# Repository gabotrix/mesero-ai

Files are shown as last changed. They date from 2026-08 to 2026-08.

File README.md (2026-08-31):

<div align="center">

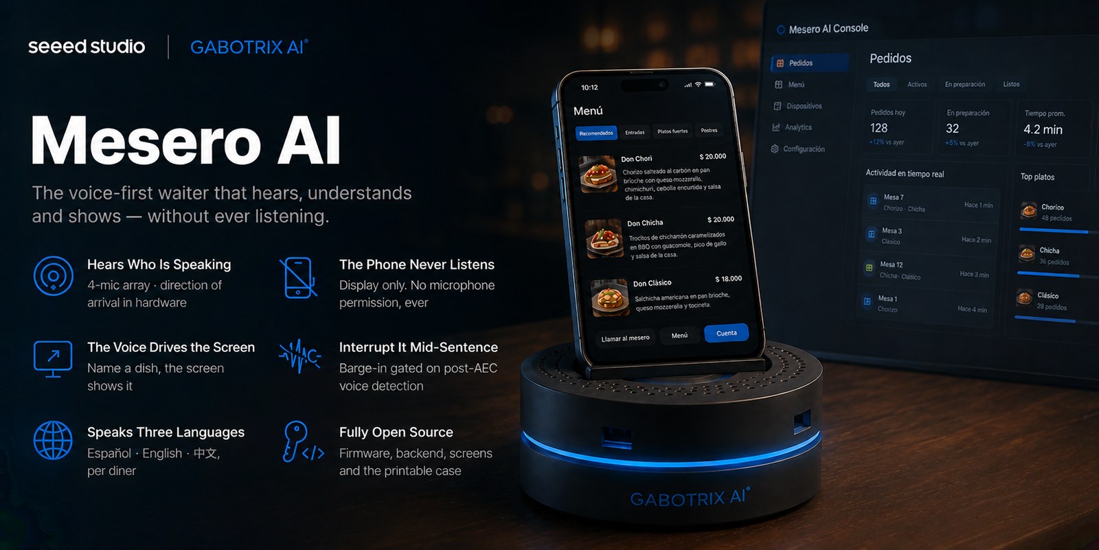
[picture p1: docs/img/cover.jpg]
Mesero AI — the voice-first waiter that hears, understands and shows, without ever listening. The printed dock holds a phone showing the menu, with the console behind it.


# Mesero AI

**A voice waiter that lives in the table, not in the phone.**

Diners talk to the table. The gadget listens and answers.
Their phone only follows along — and never asks for a microphone.






</div>

---

## The idea

A diner sits down, taps an NFC sticker on the table stand, and their phone opens
a screen bound to that table. From then on they simply **talk**. The order
appears on the screen as they say it, the kitchen sees it, the bill is paid from
the same page.

The interesting part is what the table hears. The reSpeaker's four-microphone
array reports the **direction** every phrase came from, so the agent knows *who
at the table is speaking* — and the ajiaco goes to the person who asked for it,
without anybody typing a seat number.

<div align="center">
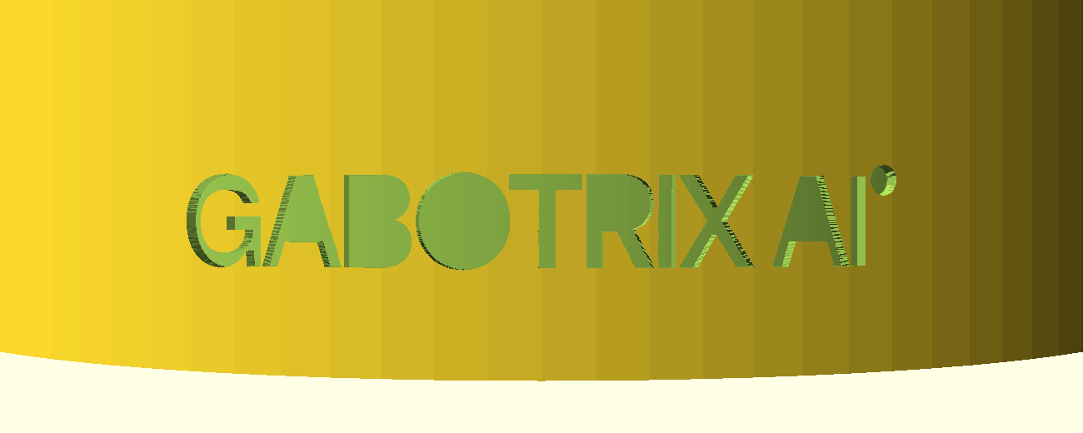
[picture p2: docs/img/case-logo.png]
The wordmark sunk into the front wall of the printed base

</div>

## Why the phone never touches the hardware

This is the decision everything else follows from.

iOS Safari has neither Web Bluetooth nor Web Serial, so a phone cannot pair with
the gadget even if we wanted it to. It also drops microphone permission the
moment the screen locks, which makes phone-side capture useless for a device
sitting on a table for an hour.

So the two never talk to each other. Both open a plain WebSocket to the backend
and are matched by a `dock` id — which is exactly what the NFC tag encodes.

```mermaid
flowchart LR
  A["reSpeaker XVF3800<br/>+ XIAO ESP32S3"] -- "WiFi · PCM16 16 kHz" --> B["Backend<br/><i>session, order, seats</i>"]
  C["Diner's phone<br/><i>NFC: ?dock=mesa-01</i>"] -- "WebSocket · display only" --> B
  B -- "realtime audio" --> D["Voice model"]
  B --> E["Kitchen board"]
  B --> F["POS · carta, tables"]
```

The tag is a passive NTAG213 sticker in the stand — no power, no pairing, and
every iPhone since the XS reads it natively. The board has no NFC and needs none.

## The firmware is deliberately dumb

It carries; it does not decide. It moves already-clean 16 kHz audio between I2S
and a WebSocket and reports the bearing. It does not know the menu, when a turn
ended, or which vendor answers.

That is on purpose, for four reasons: changing the menu must not mean unscrewing
a table; restarting a server takes a second where flashing and re-provisioning
take minutes; less code on the device is fewer failures somewhere with no serial
monitor attached; and the XMOS chip already does echo cancellation, beamforming
and noise suppression **in silicon**, so repeating it here would be slower and
worse.

## Build one

[`docs/build-guide.md`](docs/build-guide.md) takes you from an empty desk to a
table that takes an order out loud — about three hours, most of it printing. It
includes the calibration coupon to print before you commit four hours to a lid,
and a troubleshooting section where every entry is a failure we actually hit,
with what it looked like at the time.

## Quick start

You need the two Seeed boards, a speaker, and about twenty minutes.

```bash
git clone https://github.com/gabotrix/mesero-ai.git && cd mesero-ai
cd backend && npm install && node src/index.js
```

Open `http://localhost:8787/?dock=mesa-01` and the table screen is there, on the
carta committed in `backend/menu.json`, with the kitchen board and the POS
alongside it. No account and no configuration.

**The voice needs a venue key.** That part is a hosted service, and the key is
what identifies a restaurant to it. Create one in the console — free, self-serve
— and set one variable:

```bash
VENUE_KEY=msr_live_…
```

That is the whole configuration. No project ids, no API keys, nothing else: the
venue key is the only credential this backend ever carries, and its carta, its
tables and its agent arrive with it. The backend caches them to disk, so a
restaurant whose internet drops at seven in the evening still serves dinner.

Or bring your own. `PROVIDER=openai` talks to OpenAI with your credential;
`PROVIDER=local` talks to a model on your own hardware and keeps working when the
internet does not. Both mean you host the backend — we cannot reach a model on
your LAN, and we should not be holding your vendor key. The contract for a local
one is in [`docs/voz-local.md`](docs/voz-local.md); an adapter is about a hundred
lines.

Everything else in this repository runs without any of that — the wire protocol,
the firmware, the order state, the screens, the case.

No hardware yet? `device-client/` is a Python stand-in that speaks the same
protocol using your laptop's microphone.

## Bill of materials

| Part | Why |
| --- | --- |
| [reSpeaker XVF3800 + XIAO ESP32S3](https://wiki.seeedstudio.com/respeaker_xvf3800_xiao_getting_started/) | Four-mic array with hardware AEC, beamforming and direction of arrival |
| 8 Ω speaker, 50 × 45 × 22 mm | Seeed 114993346 fits the printed bay exactly |
| NTAG213 sticker, 25 mm | Passive. Sits under the phone cradle |
| ~90 g PETG | The case. PLA warps in a kitchen |
| 4 × M3 × 12 screws | Lid to base |

## Build it

**1 · Print the case.** Parametric OpenSCAD in [`hardware/case/`](hardware/case/).

```bash
openscad -D 'part="base"' -o base.stl hardware/case/mesero-dock.scad
openscad -D 'part="lid"'  -o lid.stl  hardware/case/mesero-dock.scad
```

Print `calib.stl` first — it verifies the mount circle and the connector cutouts
before you commit four hours to the lid. PETG, 0.2 mm, 4 walls, 25% infill.

<div align="center">
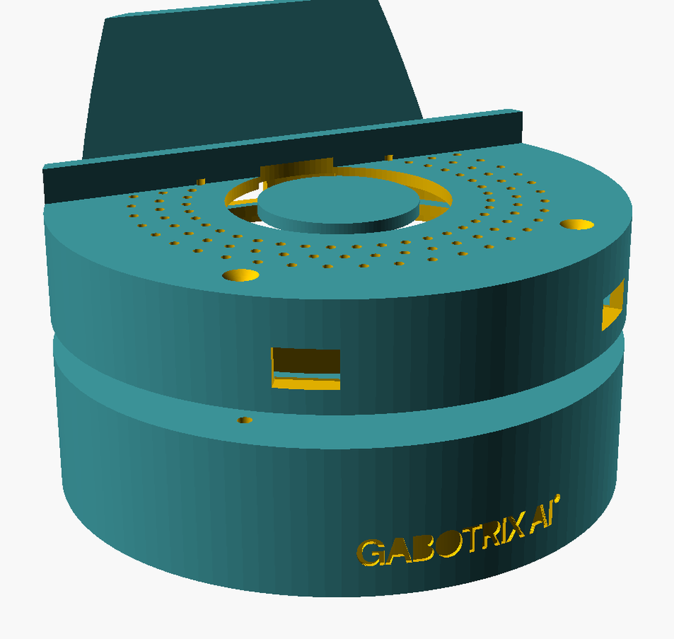
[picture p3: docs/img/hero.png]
The printed dock: a cylinder the size of the board, with a phone leaning into its cradle

</div>

**2 · Flash the firmware.**

```bash
cd firmware && pio run -t upload
```

On first boot it raises a WiFi portal named **MeseroAI-setup**. Join it from a
phone and the setup page asks for the network, the table id and the venue key —
or scan the QR the console prints for that table and every field arrives filled.

**3 · Run the backend.** Locally as above, or as a container:

```bash
docker build -t mesero-ai .
docker run -p 8787:8787 -e VENUE_KEY=msr_live_… mesero-ai
```

`deploy/cloud/` adds Caddy in front of it, which obtains and renews the
certificate on its own.

See [`docs/servidor.md`](docs/servidor.md) for where it should live and why a
diner's mobile data settles the question.

## What is in here

| Path | What it is |
| --- | --- |
| [`docs/build-guide.md`](docs/build-guide.md) | **Start here.** Empty desk to a talking table, and what every failure looks like when it happens |
| [`docs/protocolo.md`](docs/protocolo.md) | **The contract.** Binary audio frames plus JSON control, implemented identically by the firmware and the desktop client |
| [`firmware/`](firmware/) | ESP32S3 firmware — I2S, WebSocket, LED ring, setup portal |
| [`backend/`](backend/) | Session bridge: device audio ⇄ model, order state, screen fan-out |
| [`web/`](web/) | Table screen, kitchen board and POS. Static, no build step |
| [`hardware/case/`](hardware/case/) | Parametric case and phone cradle |
| [`device-client/`](device-client/) | Python stand-in for the gadget |
| [`deploy/`](deploy/) | Container and appliance deployments |
| [`docs/voz-local.md`](docs/voz-local.md) | Running the voice model on your own hardware |

## Design decisions worth knowing

Every one of these is a bug we shipped first.

**A turn ends when the speaker stops, not when the model does.** The backend
meters audio to the device at real time, so playback trails generation by the
length of the queue. Ending the turn at `turnComplete` opens the microphone while
the speaker is still talking — and the agent hears itself, answers itself, and
orders its own dinner.

**Barge-in is gated on the array's hardware VAD, not on level.** Measured echo
peaked at 22099 against speech at 32767; no threshold separates those reliably.
The XMOS chip already knows whether a human is talking, so ask it.

**Bearings are sampled while somebody speaks, never at tool-call time.** The
model answers seconds after a diner stops, by which point the azimuth register
holds something stale. Reading it there produced phantom customers sitting at
exactly 0° and exactly 90°.

**Every tuning constant is asserted numeric at boot.** Three of them were once
missing from the config, and `n >= undefined` is quietly `false` — so the
features simply switched themselves off with no error anywhere.

## License

Apache License 2.0 — see [LICENSE](LICENSE).

The hosted voice service that a venue key unlocks is operated by GABOTRIX and is
not part of this repository. Everything needed to build the device and run your
own server is.

<div align="center">
<sub>Built by <a href="https://gabotrix.com"><b>GABOTRIX</b></a> · OPENMARKT S.A.S.</sub>
</div>

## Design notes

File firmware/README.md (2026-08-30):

# Gadget firmware — reSpeaker XVF3800 + XIAO ESP32S3

The XMOS keeps its factory **I2S firmware** and does the hard part in silicon:
acoustic echo cancellation, beamforming, noise suppression, voice activity
detection and direction of arrival. This firmware only moves clean 16 kHz audio
between I2S and a WebSocket, and reports which seat is talking.

## Two ways to use the board, and which one you want

The board has two USB-C ports and two firmware personalities. Confusing them is
the single most common way to lose an afternoon.

| Port | Purpose |
|---|---|
| On the **XIAO module** | Flashing and serial for the ESP32S3 (`VID_303A`, `PID_1001`). Never carries audio. |
| On the **base board**, next to the 3.5 mm jack | XMOS: USB audio *and* DFU firmware updates. |

| Mode | What you get | When to use it |
|---|---|---|
| **I2S** (factory default) | The XIAO reads the array over I2S and streams over WiFi. The board does **not** enumerate on USB at all. | The product. This firmware. |
| **USB** | The array is an ordinary USB microphone and speaker on a PC. The XIAO is out of the audio path. | Fastest way to demo the array with `device-client/`, and useful for isolating audio problems. |

If nothing at all appears when you plug the base-board port in, that is not a
broken cable — it is I2S mode behaving exactly as documented.

## Switching modes (DFU)

Flashing the XMOS needs **safe mode**, because the I2S firmware does not support
USB DFU on its own.

1. Connect the **base board** USB-C port — the one next to the 3.5 mm jack.
2. Hold the **Mute** button, and while holding it, reconnect power.
   The red LED starts blinking: that is safe mode.
3. Flash:

```bash
dfu-util -R -e -a 1 -D respeaker_xvf3800_usb_dfu_firmware_v2.0.x.bin
```

Firmware images live in the
[reSpeaker_XVF3800_USB_4MIC_ARRAY](https://github.com/respeaker/reSpeaker_XVF3800_USB_4MIC_ARRAY)
repository:

| File | Mode |
|---|---|
| `respeaker_xvf3800_usb_dfu_firmware_v2.0.x.bin` | USB, 2 channels |
| `respeaker_xvf3800_usb_dfu_firmware_6chl_v2.0.x.bin` | USB, 6 channels |
| `respeaker_xvf3800_i2s_dfu_firmware_v1.0.x.bin` | I2S — flash this to come back |

It is fully reversible. Going to USB mode to demo and back to I2S mode to ship is
a normal thing to do.

Get `dfu-util` with `brew install dfu-util`, `sudo apt install dfu-util`, or the
Windows binaries from the dfu-util site (add the folder to `PATH`, then check
with `dfu-util -V`).

## Pinout

Confirmed against Seeed's own I2S and UDP-streaming examples for this board.

| Signal | GPIO |
|---|---|
| I2S BCLK | 8 |
| I2S WS / LRCLK | 7 |
| I2S data out (→ speaker) | 44 |
| I2S data in (mics →) | 43 |
| XMOS control | I2C, address `0x2C` |

The XMOS delivers **16 kHz, stereo, 32-bit**; the wire protocol is 16-bit mono.
The conversion — left channel, top 16 bits — is in `captureAndSend()`.

### XMOS control registers

| Function | ResID | Cmd | Notes |
|---|---|---|---|
| DOA value | 20 | 18 | 4 bytes: `uint16` azimuth 0–359, `uint16` speech flag |
| LED effect | 20 | 12 | |
| LED brightness | 20 | 13 | |
| LED speed | 20 | 15 | |
| LED colour | 20 | 16 | 3 bytes RGB |

Direction of arrival and voice activity come straight from the array, which is
why the protocol carries `doa` in the audio header instead of guessing on the
microcontroller.

## Build and flash

```bash
cd firmware
pio run                 # compile
pio run -t upload       # flash over the XIAO's USB-C port
pio device monitor      # serial log
```

Without `pio` on your PATH, use `python -m platformio` instead.

## Provisioning

No credentials are compiled in. On first boot the gadget opens a WiFi access
point called **`MeseroAI-setup`**. Join it and a captive portal asks for:

- the WiFi network and password
- the backend host or IP, and port (default `8787`)
- the table id — the `dock`, which must match the NFC tag's `?dock=` value

Settings persist in NVS. To forget them, hold the **BOOT** button on the XIAO
while resetting; the portal reopens.

## What the LED ring is telling you

| Colour | Meaning |
|---|---|
| Barely lit | Idle — nobody has woken the table |
| Amber | Listening |
| Violet | Thinking |
| Warm orange | The agent is talking |

## Behaviour worth knowing

**The microphone never mutes.** The gadget streams even while the agent speaks,
because the XVF3800 removes the speaker's echo in hardware. That is what makes
interrupting it feel natural.

**Barge-in is obeyed instantly.** On `audio_reset` the firmware clears both its
ring buffer and the I2S DMA buffers. Draining a queued sentence after the diner
starts talking is what makes a voice assistant feel deaf.

**Playback is capped at 400 ms.** If the network stalls and recovers, the gadget
drops the backlog rather than replaying a sentence that is no longer relevant.

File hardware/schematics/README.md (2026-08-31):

# Schematics

Two drawings. Between them they account for every connection in the build.

| File | What it shows |
|---|---|
| `mesero-ai-conexiones` | The whole system: the dock, the diner's phone, your server, and which of them are wired to which. The short answer is that the phone is wired to nothing. |
| `mesero-ai-pines` | The six signals that cross between the XIAO and the XVF3800, with the pin each one lands on. |

Each exists as `.svg` (source), `.png` (2× for the web) and `.pdf` (for print).

## There is no circuit to draw

This is worth saying plainly, because a project with a microphone array and an
amplifier sounds like it should have one. It does not. The XIAO seats directly
onto the reSpeaker's 14-pin header, the speaker plugs into a connector that is
already fitted, and the NFC tag is a passive sticker with no electrical
connection to anything. Nothing is soldered during the build and there is no
breadboard stage.

What *is* worth drawing is the signal map, because those pin numbers are the
part you cannot guess, and the isolation between the phone and the gadget,
because it is the design decision the whole project rests on.

## Where the numbers come from

Every pin in `mesero-ai-pines` is read out of the firmware in this repository,
not from a datasheet:

| Signal | GPIO | XIAO pin | Read from |
|---|---|---|---|
| I²S BCLK | 8 | D9 | `firmware/src/main.cpp` — `PIN_I2S_BCLK` |
| I²S WS | 7 | D8 | `firmware/src/main.cpp` — `PIN_I2S_WS` |
| I²S DOUT | 44 | D7 | `firmware/src/main.cpp` — `PIN_I2S_DOUT` |
| I²S DIN | 43 | D6 | `firmware/src/main.cpp` — `PIN_I2S_DIN` |
| I²C SDA | 5 | D4 | `Wire.begin()` with no arguments — the XIAO ESP32S3 variant default |
| I²C SCL | 6 | D5 | as above |
| BOOT | 0 | — | `firmware/src/main.cpp` — `PIN_BOOT_BUTTON` |

The XVF3800 answers on I²C address `0x2C` at 100 kHz (`firmware/src/xvf3800.h`).

## Regenerating them

```bash
pip install svglib reportlab rlPyCairo
python esquemas.py
```

The drawings are generated rather than drawn by hand so that a pin which moves
in the firmware can be corrected in one place. Arrowheads are emitted as
polygons instead of SVG markers on purpose: the renderer that produces the PNG
and the PDF ignores markers, which would quietly strip every direction out of a
signal diagram and leave it looking finished.

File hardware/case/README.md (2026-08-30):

# Table dock — 3D printable enclosure

A cylinder the size of the board, with a small cradle standing on the lid. The
array lies flat on top facing the room, the 5 W driver fires down through the
floor beneath it, and the phone leans back against the cradle. That is the whole
object — no rear lobe, no slots, no pockets.

## Dimensions, and where they come from

These are read from the Seeed datasheets, not estimated:

| Value | Source |
|---|---|
| Board ⌀ 102 × 10 mm | `114993700` — listed as 102 × 102 × 10, and the board is round, so that is a boxed circle |
| Microphone circle 66 mm | `114993700` comparison table, XVF3800 column |
| Speaker 50 × 45 × 22 mm | `114993346` — rectangular with mounting ears |

Still unverified, and the reason the coupon exists:

| Parameter | What to measure |
|---|---|
| `mount_hole_dia` | The screw holes on the board |
| `mount_circle_dia` | Diameter of the circle those holes sit on |
| `mount_first_angle` | Where the first hole sits, measured from the front |

## Resulting dock

```
diameter    107.5 mm — a circle, nothing more
body        44.8 mm tall
overall     74.8 mm with the backrest
cradle      66 mm wide, 30 mm backrest, 15 mm gap, leaning 14 deg
```

## Print the coupon first

```bash
openscad -D 'part="calib"' -o calib.stl mesero-dock.scad
```

Ten minutes of filament against four hours for the base. Drop the board in: if
the screws miss, fix `mount_circle_dia` and `mount_first_angle` before printing
anything else.

## Parts

```bash
openscad -D 'part="base"' -o base.stl mesero-dock.scad
openscad -D 'part="lid"'  -o lid.stl  mesero-dock.scad
```

| Part | Notes |
|---|---|
| `base` | Speaker bay, floor vents, cable route, feet |
| `lid` | Microphone ports on the 66 mm circle, LED slot, connector cutouts, phone cradle, NFC pocket |
| `calib` | Fit gauge |

## Print settings

| Setting | Value | Why |
|---|---|---|
| Material | PETG | A table gets wiped with hot cloths and sits in sunlight; PLA sags |
| Nozzle | 0.4 mm | The microphone ports are 1.8 mm |
| Layer | 0.2 mm | |
| Infill | 20 % gyroid | Damps the panel resonance a 5 W driver excites |
| Supports | None | The groove leans 18 deg off vertical; ports print vertically |

## Bill of materials

| Item | Qty |
|---|---|
| M3 × 12 self-tapping screws | 4 |
| 12 mm silicone feet | 3 |
| NTAG213 sticker, 25 mm round | 1 |
| Speaker 114993346 | 1 |

## Three things the renders caught

Each of these was found by looking at an orthographic view, not by reading the
code. Render before printing.

**The board is 102 mm, not 65.** The first version was built around a guess.
Reading the datasheet replaced six estimates with three measured values.

**Ports drilled straight through the cradle.** The microphone holes were cut
after the cradle was unioned onto the plate, so every hole under the backrest
went through it. They are now cut to the plate thickness only, and skipped
entirely in the sector the cradle occupies — a hole into solid plastic is not a
port, it is a weakened joint.

**Strength had to come from the attachment, not the shape.** A flat 3 mm plate
standing 30 mm tall, printed with its layers lying in the bending plane, snaps at
the root the first time somebody leans a phone on it — and the gussets propping
it up poked outside the case.

Curving the wall to follow the rim fixed the strength and broke the function: a
phone is flat, so it touched a concave wall only at its two edges and rocked
between them. The contact face is flat again, and the wall now spans a chord and
is intersected with the body, so both ends merge into the case rim. That makes it
a beam held at both ends rather than a plate cantilevered off the lid, which is
the thing that fails. Its section runs 6.2 mm at the root to 3.2 mm at the lip.

**The lean was mirrored.** The first version reclined the phone forward, over the
microphone array. Sign error in the rotation, caught in an orthographic side
view — never in isometric.

**A phone stand on top shadows the rear microphone.** This is unavoidable, not a
bug: something has to hold the phone, and it has to stand somewhere. The cradle
sits at the rim to shadow as little of the band as possible, and the diner is in
front of the dock, where the array is unobstructed.

## Still to verify on the bench

- The three mounting parameters above
- Whether the connector cutout angles in `lid()` match how the board is rotated
  when it is fitted — those are placed, not measured

## The maker's mark

The GABOTRIX wordmark is sunk 0.8 mm into the front wall of the base, to be
filled by hand after printing — paint, a drop of resin, or a scrap of filament
pressed in warm.

It is **wrapped** around the cylinder, not projected flat onto it, and that is
not a stylistic choice. A 40 mm chord on this 53.75 mm radius falls 3.9 mm away
from the surface at its ends, while the wall is only 2.4 mm thick: a
flat-bottomed pocket would cut clean through the case before it reached the
middle of the word. So the outline is sliced into 60 thin vertical strips and
each is cut radially at its own angle, which keeps the depth the same everywhere.

The outline lives in `gabotrix-logo.svg`, traced from the PNG. To use a different
mark, replace that file and adjust `logo_aspect` to its width ÷ height. To move
or resize it:

| Parameter | What it does |
|---|---|
| `logo_w` | Arc length along the wall, in mm. |
| `logo_z` | Height of its centre above the table. |
| `logo_depth` | Recess depth. Keep it well under `wall` (2.4 mm). |
| `logo_angle` | Where it sits. 90° faces the diner; the cable exit is at 270°. |
| `logo_slices` | Strips used to bend it. 60 keeps the error under a micron. |

Set `logo_w = 0` to leave the wall plain — but note the recess is what makes the
case feel finished, and it costs nothing to print.

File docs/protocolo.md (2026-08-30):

# Protocolo dispositivo ↔ backend (v1)

Este documento es **normativo**: el firmware del ESP32S3 y el cliente mock de escritorio
deben implementarlo de forma idéntica. Si cambias algo aquí, cambian los dos.

## 1. Transporte

Un único WebSocket por dispositivo.

```
ws://<host>:8787/device?dock=mesa-01&token=<device_token>
```

| Parámetro | Obligatorio | Descripción |
|---|---|---|
| `dock` | sí | Identificador de la mesa/soporte. Es lo que ata el gadget a la pantalla del teléfono. |
| `token`  | no (dev) | Token del dispositivo. En desarrollo se acepta ausente. |

Sobre ese mismo socket viajan dos tipos de frame, y **el tipo de frame decide el
significado**:

- **Frames de texto** → mensajes de control en JSON.
- **Frames binarios** → audio PCM.

Esta separación evita base64 (que infla 33 % y quema CPU en el ESP32) y permite al
firmware escribir el audio directo desde el buffer de I2S.

## 2. Frames binarios de audio

Cabecera de **8 bytes**, little-endian, seguida de las muestras PCM.

```
 offset  size  campo      descripción
 ------  ----  ---------  ----------------------------------------------------
   0      1    magic      0xA5
   1      1    version    0x01
   2      1    type       0x01 = mic (dispositivo → backend)
                          0x02 = speaker (backend → dispositivo)
   3      1    flags      bit0 = VAD activo
                          bit1 = fin de locución
                          bit2 = frame de confort/silencio
   4      2    seq        uint16, incrementa por frame, envuelve en 0xFFFF
   6      2    doa        uint16, grados 0..359. 0xFFFF = desconocido
   8      N    pcm        PCM16 little-endian, mono
```

**Formato de audio fijo en v1:** 16 kHz, 16 bits con signo, mono.
**Tamaño de frame recomendado:** 20 ms = 320 muestras = 640 bytes de PCM → 648 bytes en total.

> El backend reamplifica/reamostrea a lo que pida el proveedor de voz (hoy 24 kHz).
> El dispositivo **siempre** habla 16 kHz. Así el firmware queda tonto y estable.

`doa` viaja en la cabecera de audio, no en JSON, porque cambia por frame y sirve para
saber **quién** de la mesa está hablando sin coste de parseo.

## 3. Mensajes JSON — dispositivo → backend

Todos llevan `t` (type).

### `hello` — primer mensaje tras conectar
```json
{
  "t": "hello",
  "proto": 1,
  "dock": "mesa-01",
  "device": { "id": "xiao-68ee8f51e544", "model": "respeaker-xvf3800", "fw": "0.1.0" },
  "audio":  { "rate": 16000, "bits": 16, "ch": 1, "frameMs": 20 },
  "caps":   ["doa", "vad", "aec", "beamforming"]
}
```

### `telemetry` — máximo 5 Hz
```json
{ "t": "telemetry", "vad": true, "doa": 143, "rms": 2210 }
```

### `button` — pulsador físico del soporte
```json
{ "t": "button", "id": "call_waiter" }
```

### `bye`
```json
{ "t": "bye", "reason": "power_off" }
```

## 4. Mensajes JSON — backend → dispositivo

### `welcome` — respuesta a `hello`
```json
{
  "t": "welcome",
  "session": "s_9f3a…",
  "audio": { "rate": 16000, "bits": 16, "ch": 1, "frameMs": 20 },
  "keepaliveMs": 15000
}
```

### `agent_state` — para LEDs y para saber si hay que atenuar el micrófono
```json
{ "t": "agent_state", "state": "listening" }
```
`state` ∈ `idle` | `listening` | `thinking` | `talking`.

### `audio_reset` — **barge-in**
```json
{ "t": "audio_reset" }
```
El dispositivo debe **vaciar de inmediato** su buffer de reproducción y callar el parlante.
Es el mensaje más importante para que la interrupción se sienta natural: si el firmware
sigue drenando su buffer, el cliente escucha al agente hablando encima de él.

### `led`
```json
{ "t": "led", "mode": "listening", "doa": 143 }
```

### `ping` / `pong`
El backend manda `{"t":"ping","ts":…}` cada `keepaliveMs`. El dispositivo responde
`{"t":"pong","ts":…}` con el mismo `ts`. Si el dispositivo no ve un `ping` en
`3 × keepaliveMs`, reconecta.

## 5. Reglas de comportamiento

1. **Orden de apertura.** El dispositivo no envía audio hasta recibir `welcome`.
2. **Reconexión.** Backoff exponencial con jitter: 0.5 s, 1 s, 2 s, 4 s, máx. 10 s.
   Al reconectar con el mismo `dock`, el backend reengancha la sesión existente si
   sigue viva (ventana de 60 s), así el pedido no se pierde.
3. **Barge-in.** El dispositivo transmite el micrófono **siempre**, incluso mientras el
   agente habla. El AEC del XVF3800 ya quita el eco del parlante, así que no hay que
   silenciar el micro. La decisión de interrumpir la toma el backend.
4. **Jitter buffer.** El dispositivo debe acumular ~60 ms antes de empezar a reproducir,
   y descartar el frame más viejo si el buffer supera 400 ms.
5. **Sin audio que enviar.** Si no hay voz, el dispositivo puede omitir frames; no debe
   mandar silencio continuo salvo que quiera mantener el AEC alimentado (`flags` bit2).

## 6. Canal de la pantalla (backend ↔ Web UI)

Segundo WebSocket, **solo JSON**, que es lo que hace que el teléfono siga al gadget:

```
ws://<host>:8787/ui?dock=mesa-01
```

El backend manda un `snapshot` al conectar y luego parches:

```json
{ "t": "snapshot", "session": "s_9f3a…", "agentState": "listening",
  "screen": "menu", "order": { "items": [], "total": 0 }, "transcript": [] }

{ "t": "agent_state", "state": "talking" }
{ "t": "transcript", "role": "user", "text": "quiero una bandeja paisa" }
{ "t": "order", "items": [ { "sku": "bandeja-paisa", "qty": 1, "price": 32000 } ], "total": 32000 }
{ "t": "screen", "name": "order_review" }
{ "t": "payment", "status": "pending", "url": "https://checkout.wompi.co/l/…" }
```

Además, para que la pantalla y el POS sigan la cocina y la carta en vivo:

```json
{ "t": "vad", "vad": true }
{ "t": "menu", "menu": { "restaurant": "…", "categories": [ … ] } }
```

- `vad` refleja si el micrófono está oyendo voz; la pantalla lo usa para animar
  el anillo cuando habla el cliente (cuando habla el agente ya llega `agent_state`).
- `menu` se emite a todas las mesas cuando el POS guarda la carta.

Dentro de `state` viajan también los **tickets**: cada `confirm_order` congela la
ronda en `state.tickets[]` (`{ id, n, status, sentAt }`), y los items confirmados
llevan `ticket: <id>`. `status` ∈ `kitchen` | `preparing` | `ready` | `served`, y lo
avanza el POS por HTTP:

```
PUT  /api/menu                                  guarda la carta (CRUD del POS)
POST /api/dock/:dock/ticket/:id/status          { "status": "preparing" }
POST /api/dock/:dock/reset                      libera la mesa
POST /api/dock/:dock/tool                       { "name": "add_item", "args": {…}, "doa": 40 }
```

`/tool` aplica una herramienta del pack como si la hubiera llamado el modelo —
mismo reducer, mismo fan-out — y es lo que usa un demo o un POS para editar un
pedido a mano.

La UI es **solo pantalla**: no captura audio y no manda comandos de voz. Lo único que
puede emitir es interacción táctil de respaldo:

```json
{ "t": "ui_action", "action": "call_waiter" }
```

## 7. Por qué así

- **Un solo socket para audio y control** evita desincronización entre el estado del
  agente y el audio que se está reproduciendo, y ahorra un TLS en el ESP32.
- **Binario crudo para audio** mantiene el firmware simple y el ancho de banda bajo:
  16 kHz mono PCM16 = 256 kbps por sentido, cómodo para WiFi de restaurante.
- **El dispositivo no sabe nada del proveedor de voz.** Puede cambiarse OpenAI Realtime
  por Azure o Gemini sin tocar el firmware. Esa es la razón de que el backend reamostree
  en vez de exigirle 24 kHz al ESP32.

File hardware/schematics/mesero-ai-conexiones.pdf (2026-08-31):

# Mesero AI — connection diagram

Every connection in the build. The gadget hears; the phone only shows.

GABOTRIX AI®
reSpeaker XVF3800 + XIAO ESP32S3

ON THE TABLE — THE GADGET

## reSpeaker XVF3800

Seeed 114993700 · XMOS DSP · firmware 1.0.5
4 microphones on a 66 mm circle
Echo cancellation, beamforming, VAD, direction of arrival Class-D amplifier on board

I²S audio
16 kHz · 32 bit

I²C control
0x2C · 100 kHz

## XIAO ESP32S3

Seats on the array's 14-pin header — no loose wires Streams 20 ms PCM frames; holds Wi-Fi and the venue key BOOT on GPIO0: 3 s clears Wi-Fi · 10 s clears everything

amplified out

## Speaker · 8 Ω, 5 W

Seeed 114993346 · 50 × 45 × 22 mm Fires down through the floor of the base

USB-C — 5 V
power · flashing · provisioning

NTAG213 sticker
passive — no power, no wires

THE DINER'S PHONE

Menu
Order
Bill

Display only — never a microphone A web page, not an app
Opened by the tag: ?dock=mesa-01

tap

YOUR SERVER

## Node backend

Railway, a VPS, or a Seeed reComputer Speech in · order state · speech out
Seat attribution from the array's bearing Holds the venue key — the only credential railway.json health-checks /api/health

### Console — seeed.gabotrix.com

Menu, tables, brand, agent language
Kitchen screen — no second system to log into Flashes the gadget and puts it on the Wi-Fi, over USB from the browser (Web Serial)
Stores configuration, never a diner's order

WebSocket · binary PCM16

↕ the phone's own WebSocket — JSON screen state, no audio

No link between them, by design

The phone and the gadget never talk to each other. No Bluetooth, no pairing, no local socket.

Each opens its own connection to the backend and they are matched by the table id in the NFC tag.

That is why the phone never needs the microphone, and why a locked screen does not stop the order.

The only soldered joint in the build is the speaker's, and it arrives already made. Everything else plugs together.
Audio path: 4 microphones → XVF3800 (echo cancellation, beamforming) → I²S → ESP32-S3 → Wi-Fi → backend → back down the same socket → amplifier → speaker.

Apache-2.0 · github.com/gabotrix/mesero-ai · Seeed Interactive Signage Contest 2026

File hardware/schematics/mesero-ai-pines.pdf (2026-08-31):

# Mesero AI — board-to-board signals

Six signals cross between the two boards. Every number here is read from the firmware.

GABOTRIX AI®
No wiring — a 14-pin board-to-board seat

## XIAO ESP32S3

I²S master · Wi-Fi · USB-C

## reSpeaker XVF3800

XMOS DSP · I²S slave · amplifier

D9 · GPIO8 | I²S BCLK — bit clock | clock in
D8 · GPIO7 | I²S WS — word select | frame in
D7 · GPIO44 | I²S DOUT — the agent's voice, out to the speaker | to the amplifier
D6 · GPIO43 | I²S DIN — the room, already cleaned up | from the microphones
D4 · GPIO5 | I²C SDA — data | address 0x2C
D5 · GPIO6 | I²C SCL — clock, 100 kHz | bearing, LED ring

The audio format, both directions

16 000 Hz · 32-bit slots · stereo frame · I²S standard
One DMA block = 20 ms = 320 samples = 640 bytes of PCM16 The ESP32 is the master; the XVF3800 follows its clock
MCLK is not connected — the DSP makes its own

What I²C is for — and the trap inside it

The control channel reads which direction a phrase came from. That is what puts each dish on the right diner's tab, and what drives the LED ring.
It answers only on XVF3800 firmware 1.0.5. On 1.0.4 the register returns 65535 for ever: the gadget still takes orders, but cannot tell two diners apart.

Apache-2.0 · github.com/gabotrix/mesero-ai · Seeed Interactive Signage Contest 2026

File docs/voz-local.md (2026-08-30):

# Running the voice model yourself

Three ways to give this project a voice. Pick one with `PROVIDER`.

| | What you configure | Where the secret lives |
| --- | --- | --- |
| `gabotrix` *(default)* | A venue key | Nowhere near you |
| `openai` | Your own `OPENAI_API_KEY` | On your machine |
| `local` | A URL on your network | There is no secret |

The device, the session and the table screen cannot tell which one is running.
Adding a fourth is one file in `backend/src/providers/` and a branch in the
factory.

Note that `openai` and `local` both mean **you host the backend**. That is not a
restriction we invented — we cannot reach a model on your LAN, and we should not
be holding your vendor key.

## Why you might want `local`

Not privacy, though you get it. Not cost, though it is lower. The reason is that
a restaurant with bad internet still has to serve dinner, and every other option
here dies with the connection.

A reComputer R1025 or any small Linux box will do. What runs on it is your
choice — whisper.cpp for speech, a small instruct model, Piper for the voice —
because this project does not care, as long as the thing in front of them speaks
the envelope below.

## The contract

One WebSocket. JSON both ways. Audio is PCM16LE mono at 24 kHz, base64-encoded.
It is the same shape the hosted bridge speaks, on purpose: an adapter is about a
hundred lines, not a rewrite.

```
PROVIDER=local
LOCAL_VOICE_URL=ws://recomputer.local:8080/voice
# LOCAL_VOICE_TOKEN=            optional; a box on your own LAN has nobody to prove itself to
```

### Backend → you

| Message | When |
| --- | --- |
| `{"type":"session.update","session":{"instructions":"…","tools":[…]}}` | First thing on connect. The persona and the tools the agent may call. Ignore it and the agent still talks — it just will not know the carta. |
| `{"realtimeInput":{"audio":{"data":"<b64>","mimeType":"audio/pcm;rate=24000"}}}` | Microphone audio, continuously. |
| `{"textMessage":"…"}` | A user turn injected as text, from a button on the table screen. |
| `{"type":"response.cancel"}` | Somebody talked over the agent. Stop generating now. |

### You → backend

| Message | Meaning |
| --- | --- |
| `{"setupComplete":true}` | Ready. Nothing is sent until this arrives. |
| `{"serverContent":{"modelTurn":{"parts":[{"inlineData":{"data":"<b64>"}}]}}}` | Speech, as it is produced. Send it in pieces; do not wait for the sentence. |
| `{"serverContent":{"turnComplete":true}}` | You finished generating. |
| `{"serverContent":{"interrupted":true}}` | You noticed the diner talking over you first. |
| `{"toolCall":{"functionCalls":[{"id":"…","name":"add_item","args":{…}}]}}` | The agent wants to change the order. |
| `{"error":"…"}` | Anything that went wrong. |

## Two things that will bite you

**`turnComplete` is not the end of the turn.** It means you stopped generating.
The backend meters audio to the gadget at real time, so playback trails
generation by the length of the queue. Treating it as the end opens the
microphone while the speaker is still talking, and the agent hears itself,
answers itself, and orders its own dinner. We shipped that bug. The backend
handles this — you just need to know that `turnComplete` is about you, not about
the table.

**Send audio in pieces.** A whole sentence delivered at once overruns the
device's buffer and comes out chopped. The backend meters what you send, but it
cannot smooth what it never received.

## Latency, honestly

The hosted path answers in well under a second. A small model on a Pi-class box
will not, and the gap is most of a second of somebody sitting at a table waiting.
It is a real trade, not a footnote: a slower agent that always works may still be
the right answer for a restaurant whose internet drops at seven in the evening,
but decide it knowing that is the choice.

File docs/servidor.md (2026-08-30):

# Where the backend runs

Short answer: hosted, with a public name and a certificate. Everything else in
this page is either why, or the exception.

## The constraint that decides it

**A diner uses their own mobile data.** They tap an NFC tag and expect a page,
and they are not going to join the restaurant's WiFi first — on iOS that means
fighting a captive portal before dinner.

That single fact rules out every local arrangement for the *table screen*. A page
served from `192.168.1.50` is unreachable from a phone on a cellular network, and
a tunnel from a machine behind the bar is a workaround for a problem that
disappears if the backend simply lives somewhere with an address.

So: one hosted backend. The gadget dials `wss://` outbound from the restaurant
WiFi, the diner's phone opens `https://`, and there is nothing in the restaurant
to install, forward, or keep switched on.

## Why it cannot be a Supabase function

Four things the backend does, and none of them fit a short stateless request:

1. **Meters speech in real time.** The model emits a whole sentence at once. Sent
   onward as it arrives it overruns the device buffer and the reply comes out
   chopped, so frames go out on a 20 ms tick for the length of the meal, with
   16 ↔ 24 kHz resampling both ways.
2. **Knows when a turn ended** — when the speaker finishes, not when the model
   stops generating. Get that wrong and the agent hears itself, answers itself,
   and orders its own dinner. We shipped that bug once.
3. **Separates customers by bearing**, sampling angles only while somebody is
   actually speaking and averaging them circularly.
4. **Holds the order** and fans it out to every screen watching that table.

The Supabase function in this project does exactly one thing — relay audio to the
model — and knows nothing about tables.

## Deploying it

```bash
cp deploy/cloud/.env.example deploy/cloud/.env    # fill in the venue key
# point your domain at the host, then:
docker compose -f deploy/cloud/docker-compose.yml up -d
```

Caddy obtains and renews the certificate on its own; there is nothing else to
configure. The gadget's WebSocket and the diner's page go through the same proxy.

The gadget ships pointing at the hosted backend on port 443 and speaks TLS. The
setup portal still shows a server field, but behind a heading that says it is
only for somebody running their own — most people never touch it.

## The exceptions

**A restaurant with no reliable internet.** Then the whole thing has to be local,
including the model, and that is the offline mode — still unbuilt, and blocked on
the reComputer's power supply. Note that in this case the diner's phone must be
on the restaurant's WiFi; there is no way around it, because there is no public
address to reach.

**Somebody who wants to run their own backend** — a chain with its own
infrastructure, or a replicator who does not want to depend on us. Two supported
shapes:

- `deploy/recomputer/install.sh` — installs it as a systemd service on a
  reComputer R1025. Data lives in `/var/lib/mesero-ai` so an update never
  overwrites a carta somebody changed mid-service.
- `desktop/build.mjs` — builds the backend into a single executable for a
  Windows PC. It has no interface: it is a service, and it prints its addresses
  and then serves. If it ever becomes something a restaurant installs by itself
  it needs a real front end, and right now it is not on that path.

Both of these serve a LAN address, which means the diner's phone has to be on the
restaurant's WiFi. That is the trade, and it is the reason the hosted deployment
is the default rather than one option among three.

## Do not forward a port

If you run this locally anyway, do not open a port to it. The table screen has no
authentication — deliberately, because a diner cannot be asked to log in — and
that is only safe while reaching it requires being on the premises. Use an
outbound tunnel (`cloudflared tunnel --url http://localhost:8787`) if you need it
reachable, so there is no inbound hole in the firewall.

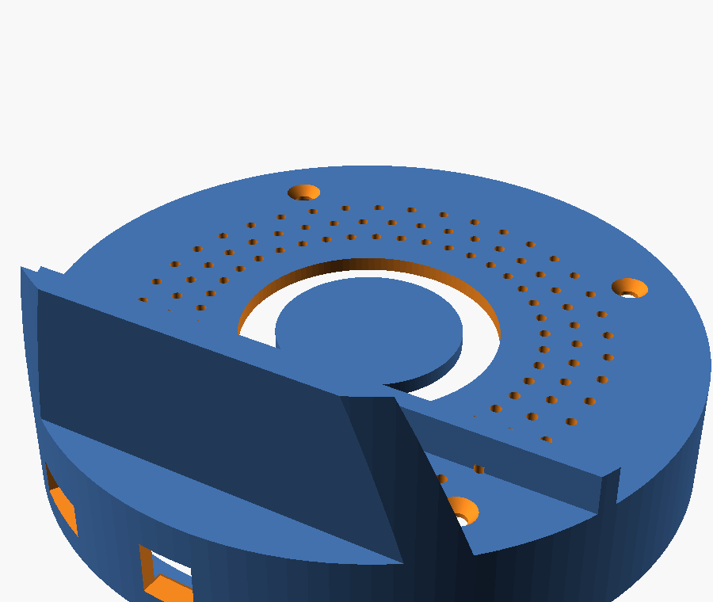
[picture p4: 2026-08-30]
hardware/case/m-iso.png

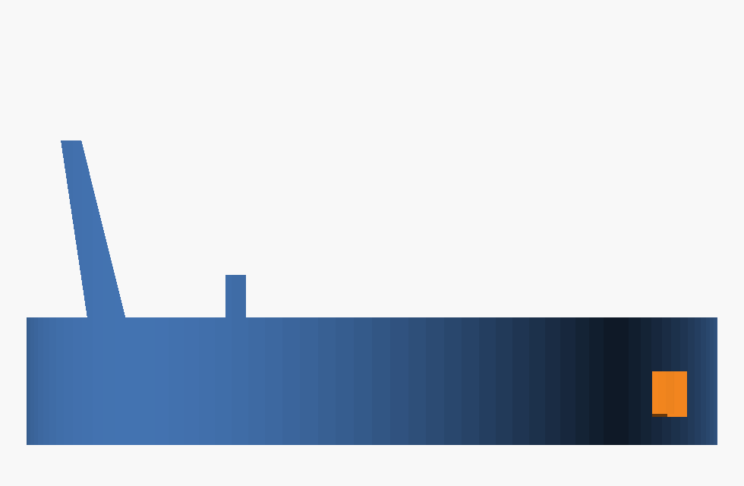
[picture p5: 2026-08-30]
hardware/case/m-side.png

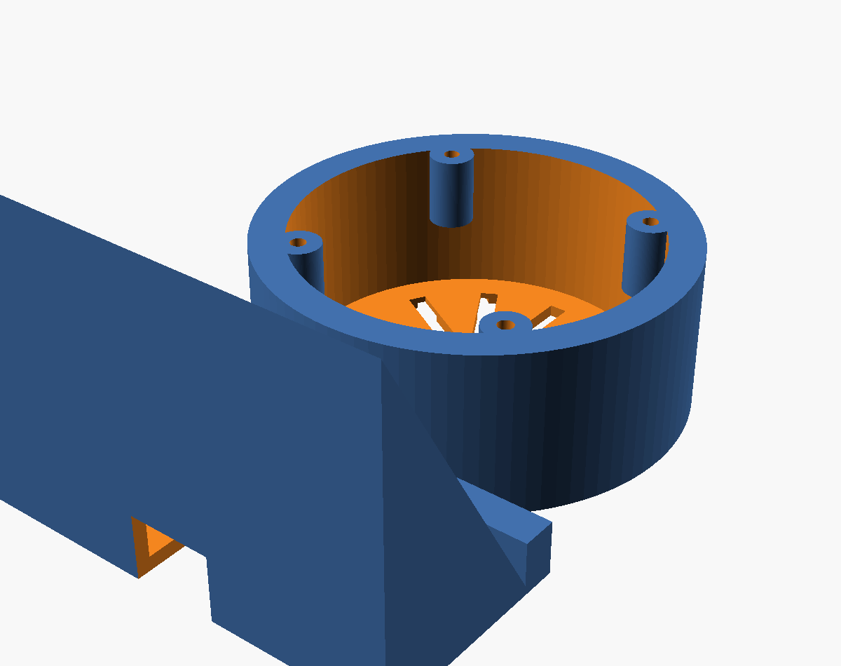
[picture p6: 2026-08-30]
hardware/case/preview-base.png

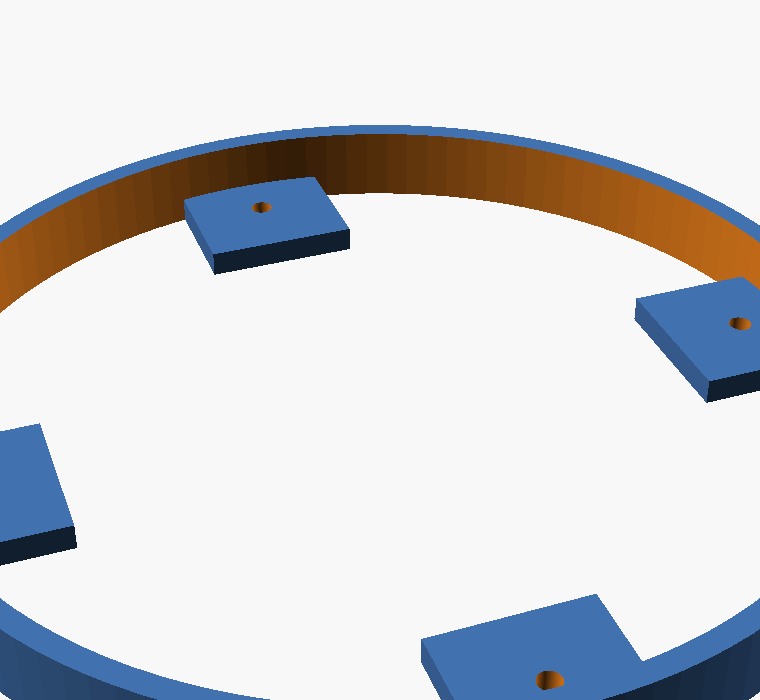
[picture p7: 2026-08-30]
hardware/case/calib-view.png

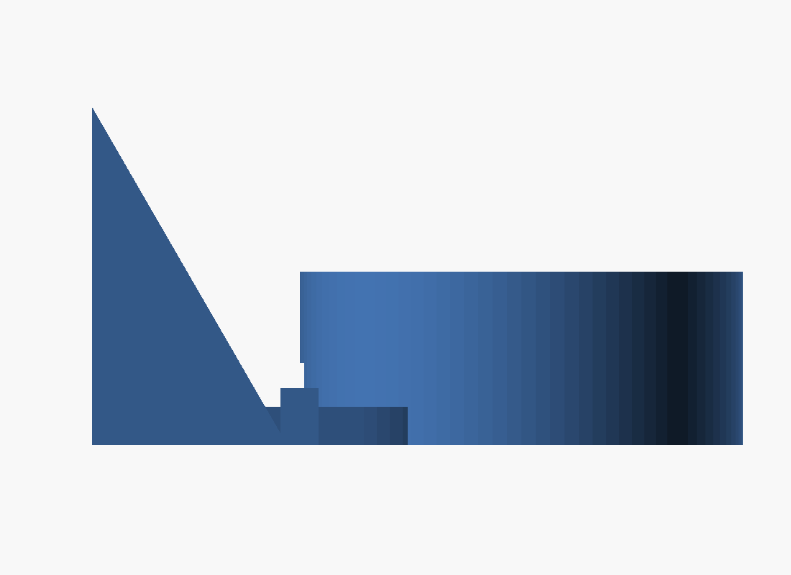
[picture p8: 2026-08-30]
hardware/case/preview-side.png

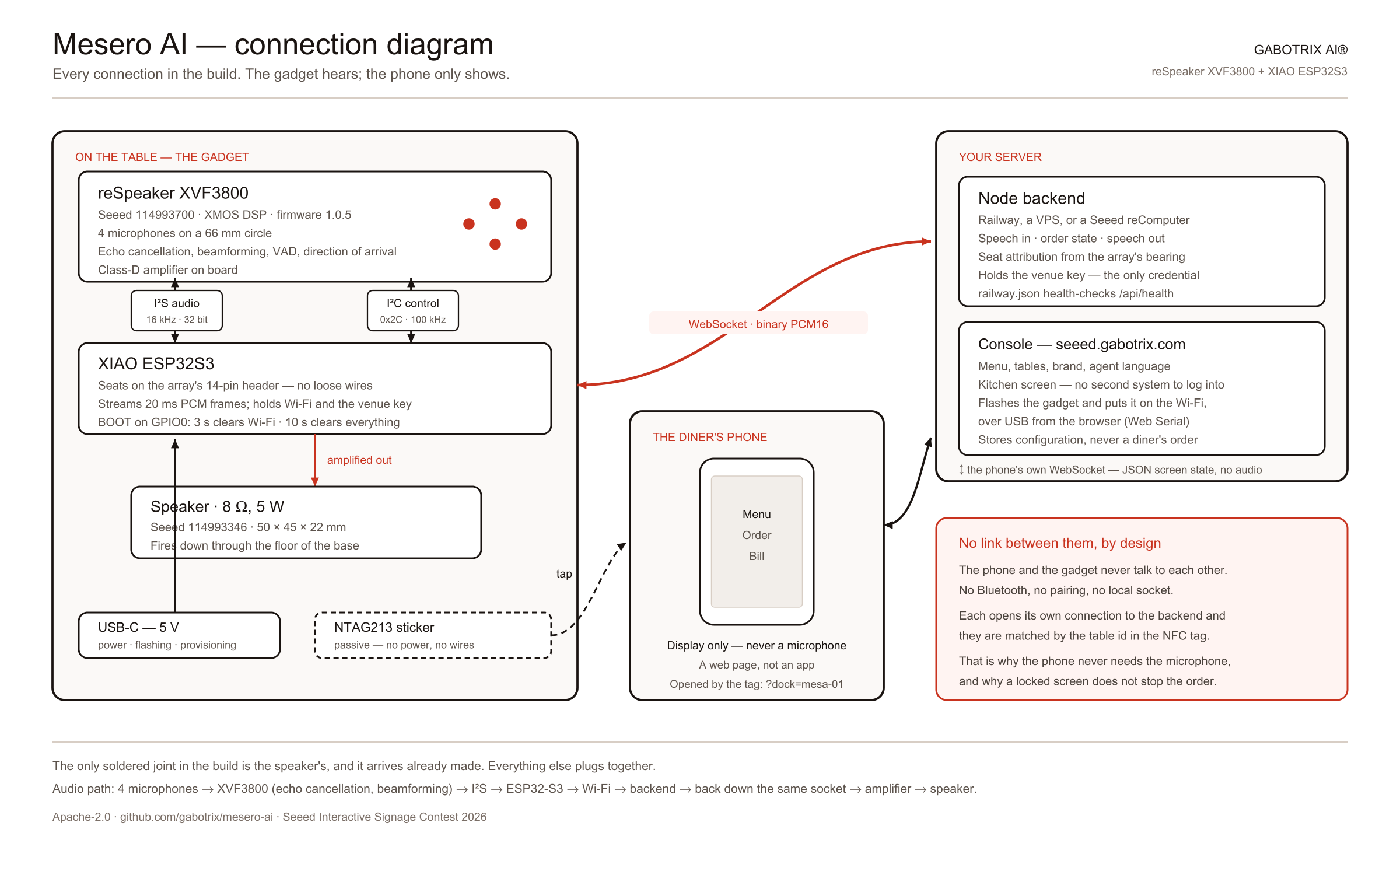
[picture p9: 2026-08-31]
hardware/schematics/mesero-ai-conexiones.png

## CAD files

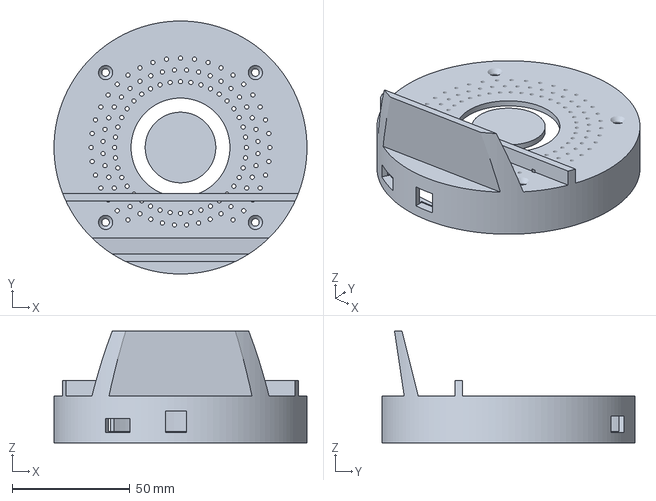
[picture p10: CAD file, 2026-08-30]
hardware/case/lid.3mf
107.5 x 107.5 x 47.4 mm

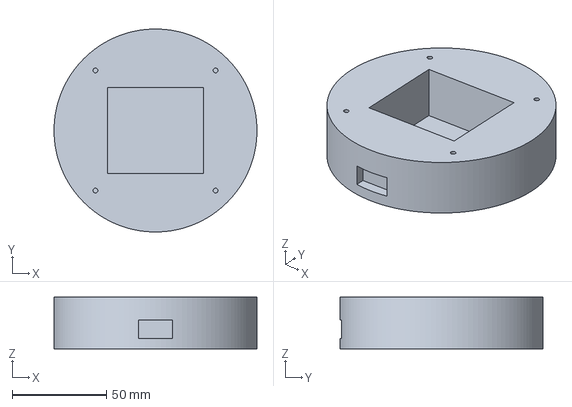
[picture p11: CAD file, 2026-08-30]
hardware/case/base.3mf
107.5 x 107.5 x 27.4 mm

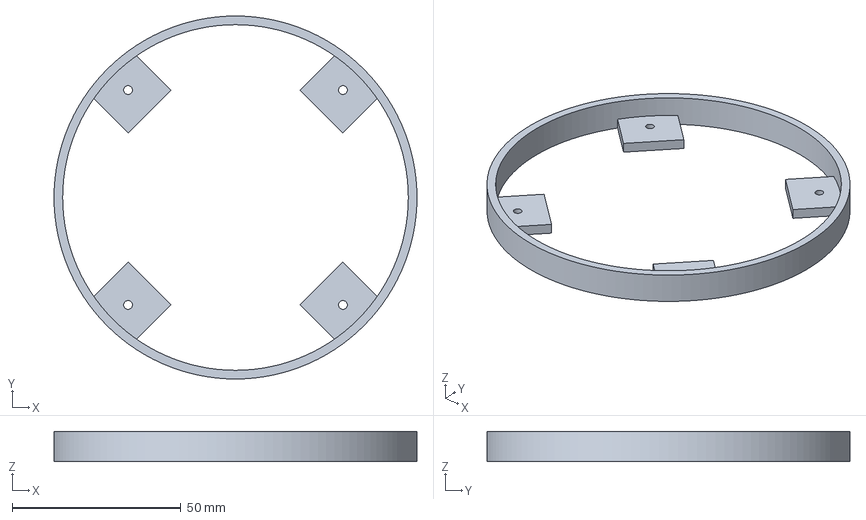
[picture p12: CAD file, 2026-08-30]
hardware/case/calib.3mf
107.5 x 107.5 x 9.00 mm

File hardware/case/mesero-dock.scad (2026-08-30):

// =============================================================================
// Mesero AI — table dock for reSpeaker XVF3800 + XIAO ESP32S3
//
// A plain cylinder the size of the board, with a small cradle on top that a
// phone leans into. Nothing else: no rear lobe, no slots, no pockets.
//
// Dimensions are from the Seeed datasheets, not estimated:
//   reSpeaker XVF3800 + XIAO   102 x 102 x 10 mm  (a 102 mm circle, boxed)
//   Microphone circle           66 mm
//   Speaker 114993346           50 x 45 x 22 mm
//
//   openscad -D 'part="base"'  -o base.stl  mesero-dock.scad
//   openscad -D 'part="lid"'   -o lid.stl   mesero-dock.scad
//   openscad -D 'part="calib"' -o calib.stl mesero-dock.scad
// =============================================================================

part = "base";   // "base" | "lid" | "calib" | "preview"

/* [Board — from the datasheet] ============================================= */

board_dia   = 102;
board_bay_h = 15;    // headroom for the board and its connectors
mic_circle  = 66;

// Not published anywhere. Verify with the coupon before printing the lid.
mount_hole_dia    = 2.6;   // VERIFY
mount_circle_dia  = 90;    // VERIFY
mount_first_angle = 45;    // VERIFY

/* [Speaker — from the datasheet] =========================================== */

speaker_l = 50;
speaker_w = 45;
speaker_h = 22;

/* [Microphone ports and LED ring] ========================================== */

mic_band_inner = mic_circle - 10;
mic_band_outer = mic_circle + 10;
mic_hole_dia   = 1.8;
mic_hole_rings = 3;
mic_holes_per_ring = 40;

led_slot_inner = 30;
led_slot_outer = 42;
led_membrane   = 0;      // 0 = open slot, 0.6 = printed diffuser

/* [Phone cradle] =========================================================== */

// A backrest and a lip standing on the lid. The phone leans back against the
// rest and gravity holds it. Placed toward the rim so the phone's lower edge
// covers as little of the microphone band as it can.
cradle_h     = 30;    // backrest height
cradle_lean  = 14;    // degrees off vertical, leaning away from the diner
cradle_gap   = 15;    // phone plus case
cradle_lip_h = 9;
cradle_t     = 3.2;   // wall thickness at the top
cradle_root  = 3.0;   // extra thickness at the root, where it wants to snap

// NTAG213, 25 mm round, right under where the phone's lower edge lands.
nfc_dia   = 27;
nfc_depth = 1.2;

/* [Maker's mark] =========================================================== */

// The GABOTRIX wordmark, sunk into the front wall so it can be filled by hand
// after printing — paint, resin or a scrap of filament pressed in warm.
//
// It is wrapped around the cylinder rather than projected flat onto it. A flat
// pocket cannot work here: a 40 mm chord on this 53.75 mm radius drops 3.9 mm
// away from the surface at its ends, and the wall is only 2.4 mm thick, so a
// flat-bottomed recess would cut straight through. Wrapping keeps the depth
// constant everywhere.
logo_file   = "gabotrix-logo.svg";
logo_aspect = 7.131;   // from the traced outline; height follows the width
logo_w      = 40;      // arc length along the wall
logo_z      = 8.5;     // height of its centre above the table
logo_depth  = 0.8;     // leaves 1.6 mm of wall behind it
logo_angle  = 90;      // 90 = facing the diner; the cable exit is at the back
logo_slices = 60;      // strips used to bend it; 60 puts the error under 1 µm

/* [Enclosure] ============================================================== */

wall     = 2.4;
floor_h  = 2.4;
fit      = 0.35;
screw_dia = 3.2;
screw_head_dia = 6.2;
boss_dia = 8;

$fn = 120;

// ----------------------------------------------------------------- derived

outer_dia = board_dia + 2 * wall + 2 * fit;   // 107.5
outer_r   = outer_dia / 2;
base_h    = floor_h + speaker_h + 3;
lid_h     = board_bay_h + wall;


module screw_positions() {
    for (i = [0 : 3])
        rotate([0, 0, mount_first_angle + i * 90])
            translate([mount_circle_dia / 2, 0, 0])
                children();
}

// ------------------------------------------------------------ acoustics

/// A perforated band centred on the 66 mm circle the datasheet gives, wide
/// enough that a couple of millimetres of placement error still finds open air.
module mic_ports() {
    step = (mic_band_outer - mic_band_inner) / 2 / max(mic_hole_rings - 1, 1);
    for (r = [0 : mic_hole_rings - 1]) {
        rad = mic_band_inner / 2 + r * step;
        off = (r % 2) * (180 / mic_holes_per_ring);
        for (a = [0 : 360 / mic_holes_per_ring : 359.9])
            // Skip the sector the cradle stands on. A hole under the backrest is
            // a hole into solid plastic, and drilling it only weakened the join.
            if (rad * sin(a + off) > -(outer_r - 16) + 4)
                rotate([0, 0, a + off])
                    translate([rad, 0, -1])
                        // Plate thickness only. Running these the full height
                        // drilled straight through the cradle above.
                        cylinder(d = mic_hole_dia, h = wall + 2);
    }
}

/// Slots in the floor under the driver. Vented rather than sealed: a 5 W driver
/// in a sealed box this size sounds thin, and open-backed it cancels itself.
module speaker_vents() {
    for (i = [-2 : 2])
        translate([i * 9, 0, -1])
            cube([4.5, speaker_w - 12, floor_h + 2], center = true);
}

/**
 * The wordmark, bent onto the wall.
 *
 * OpenSCAD cannot deform a solid, so the outline is sliced into thin vertical
 * strips and each strip is stood up at its own angle on the cylinder. Every
 * strip is cut radially, which is what makes the depth uniform — the thing a
 * flat projection gets wrong.
 */
module logo_recess() {
    if (logo_w > 0) {
    logo_h = logo_w / logo_aspect;
    step   = logo_w / logo_slices;
    r      = outer_r;

    translate([0, 0, logo_z])
        rotate([0, 0, logo_angle])
            for (i = [0 : logo_slices - 1]) {
                cx  = -logo_w / 2 + (i + 0.5) * step;
                ang = cx / r * 180 / PI;
                rotate([0, 0, ang])
                    // Start the cut inside the wall and run it past the surface,
                    // so the recess opens cleanly instead of leaving a skin.
                    translate([r - logo_depth, 0, 0])
                        rotate([90, 0, 90])
                            linear_extrude(height = logo_depth + 0.6)
                                translate([-cx, 0])
                                    intersection() {
                                        translate([-logo_w / 2, -logo_h / 2])
                                            resize([logo_w, logo_h])
                                                import(logo_file);
                                        translate([cx, 0])
                                            square([step * 1.02, logo_h * 2], center = true);
                                    }
            }
    }
}

// ---------------------------------------------------------------- parts

module base() {
    difference() {
        cylinder(d = outer_dia, h = base_h);

        // Speaker bay.
        translate([-(speaker_l + fit * 2) / 2, -(speaker_w + fit * 2) / 2, floor_h])
            cube([speaker_l + fit * 2, speaker_w + fit * 2, speaker_h + 6]);

        speaker_vents();

        // Cable exit at the back.
        translate([-9, -outer_r - 1, floor_h + 3])
            cube([18, wall + 4, 10]);

        // Screw pilots.
        translate([0, 0, base_h - 14])
            screw_positions() cylinder(d = screw_dia - 0.6, h = 16);

        logo_recess();

        // Feet.
        for (a = [30 : 120 : 359])
            rotate([0, 0, a])
                translate([outer_r - 13, 0, -0.01])
                    cylinder(d = 13, h = 1.1);
    }

    // Bosses carrying the lid screws.
    difference() {
        translate([0, 0, base_h - 14])
            screw_positions() cylinder(d = boss_dia, h = 14);
        translate([0, 0, base_h - 14.5])
            screw_positions() cylinder(d = screw_dia - 0.6, h = 16);
    }
}

/**
 * Backrest and lip.
 *
 * The contact face is flat, because a phone is flat: an arc following the rim
 * looked right and was useless — a flat phone touches a concave wall only at its
 * two edges and rocks between them.
 *
 * Strength comes from how it is attached instead of from its shape. The wall
 * spans a chord and is intersected with the body, so both of its ends merge into
 * the case rim: a beam held at both ends rather than a plate cantilevered off
 * the lid, which is what snaps. Its section runs thick at the root and thin at
 * the lip, putting material where the bending moment actually is.
 */
module phone_cradle() {
    lean = cradle_h * tan(cradle_lean);
    y0   = -(outer_r - 16);          // front face of the backrest, at the base
    yl   = y0 + cradle_gap;          // where the lip stands
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

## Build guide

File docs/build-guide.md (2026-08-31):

# Build one yourself

From an empty desk to a table that takes an order out loud. About three hours,
most of it printing.

This is written for somebody who has not seen the project before. Every number
in it was measured on a bench, and every failure in the troubleshooting section
is one we actually hit — with what it looked like at the time, which is the part
that is usually missing.

---

## What you are building

A cylinder that sits in the middle of a table and listens. A diner taps an NFC
sticker on its cradle, their phone opens a screen bound to that table, and from
then on they talk. The order appears on the screen as they say it; the kitchen
sees it; the bill is paid from the same page.

The part worth building it for: the microphone array reports the **direction**
each phrase came from, so the agent knows *who at the table is speaking*. The
ajiaco is attributed to the person who ordered it, and nobody types a seat
number.

---

## Bill of materials

| Part | Why this one | Approx. |
| --- | --- | --- |
| [reSpeaker XVF3800 + XIAO ESP32S3](https://wiki.seeedstudio.com/respeaker_xvf3800_xiao_getting_started/) | Four microphones with echo cancellation, beamforming and direction of arrival **in hardware**. This is the whole reason the project works in a noisy room. | ~US$45 |
| 8 Ω speaker, 50 × 45 × 22 mm | Seeed 114993346 fits the printed bay exactly. Any speaker of those dimensions works. | ~US$4 |
| NTAG213 sticker, 25 mm round | Passive. No power, no pairing. Every iPhone since the XS reads it natively. | ~US$0.30 |
| PETG filament, ~90 g | PLA warps near a kitchen. | ~US$2 |
| 4 × M3 × 12 mm screws | Lid to base. | — |
| USB-C cable (data, not charge-only) | For flashing. A charge-only cable is the most common first hour lost. | — |

**Software:** [PlatformIO](https://platformio.org/) (VS Code extension),
[OpenSCAD](https://openscad.org/) if you want to change the case, Node.js 20 or
newer, a slicer.

---

## Step 1 — Print the calibration coupon first

Do not print the lid yet. Print this instead; it takes ten minutes.

```bash
git clone https://github.com/gabotrix/mesero-ai.git && cd mesero-ai
openscad -D 'part="calib"' -o calib.stl hardware/case/mesero-dock.scad
```

The coupon carries the mounting circle and the connector cutouts. Two numbers in
the model — `mount_circle_dia` (90 mm) and `mount_first_angle` (45°) — are **not
published in any Seeed datasheet**. They were measured. Hold the coupon against
your board: the four holes should line up and the USB-C cutout should clear the
connector.

If they do not, edit those two values in `hardware/case/mesero-dock.scad` and
print it again. Ten minutes now against four hours of lid later.

## Step 2 — Print the case

```bash
openscad -D 'part="base"' -o base.stl hardware/case/mesero-dock.scad
openscad -D 'part="lid"'  -o lid.stl  hardware/case/mesero-dock.scad
```

PETG, 0.2 mm layers, 4 walls, 25% infill. No supports — the model is designed
without overhangs that need them. Base takes about 2 h 20, lid about 1 h 40.

**The base has the GABOTRIX wordmark sunk 0.8 mm into its front wall**, to be
filled by hand afterwards with paint or a scrap of filament pressed in warm. To
put your own mark there, replace `hardware/case/gabotrix-logo.svg` and set
`logo_aspect` to its width ÷ height. `logo_w = 0` leaves the wall plain.

The mark is *wrapped* around the cylinder rather than projected flat onto it,
and that is not decoration: a 40 mm chord on this 53.75 mm radius falls 3.9 mm
away from the surface at its ends while the wall is only 2.4 mm thick, so a
flat-bottomed pocket would cut straight through the case before it reached the
middle of the word.

## Step 3 — Assemble

1. Seat the speaker in the rectangular bay in the base. It is a friction fit.
2. Run the speaker wires up through the cable channel.
3. Set the reSpeaker board on the four bosses, microphones facing **up**.
4. Screw the lid down, 4 × M3 × 12.
5. Stick the NTAG213 under the phone cradle, on the flat.

Do not write the tag yet — you need the table's address first, in step 7.

## Step 4 — Flash the firmware

```bash
cd firmware && pio run -t upload
```

If the board is not found: hold **BOOT**, tap **RESET**, release BOOT. That puts
the ESP32-S3 into download mode. On Windows you may need
[Zadig](https://zadig.akeo.ie/) once to bind the WinUSB driver.

Watch it come up:

```bash
pio device monitor
```

You want lines like `[mic] peak=… doa=… vad=…`. If `peak` stays near zero, the
board is in USB mode rather than I2S mode — see troubleshooting.

### Check the XVF3800's own firmware version

The first line matters more than it looks:

```
[xmos] firmware 1.0.5 - read path OK
```

**It has to be 1.0.5 or newer.** On 1.0.4 the direction-of-arrival register does
not answer: `readDoa` gets a fixed error, and `doa` stays at 65535 with `vad` at
0 forever. The gadget still hears, still streams, still takes orders — it simply
cannot tell one diner from another, and the agent cannot be interrupted, because
the flag that says somebody is talking over it never arrives.

Two boards from the same order can differ. We lost an evening to it: one gadget
attributed dishes to five separate customers and its twin, running a
byte-identical build, reported nothing at all. The version line is the only
place that difference is visible before you are standing at a table wondering
why nobody is being recognised.

Seeed's updater flashes the XVF3800 over USB; it is a separate chip from the
XIAO and reflashing the ESP32 never touches it.

## Step 5 — Set up your restaurant

Go to the console, create an account and a restaurant, and build your carta:
categories, dishes, prices, photos. Add one table per gadget you are installing,
and give the agent a name and a character.

Then, under **Conexión**, generate a **venue key**. It looks like this:

```
msr_live_7f3a91c2e4b6d8005a1c9f3e2b7d4a6c8e0f1234abcd
```

Copy it now. It is shown once and only its hash is stored — we cannot read it
back to you, which is the property that makes a stolen database harmless.

> **Prefer not to use our service at all?** Skip this step. The backend runs on
> the carta committed in `backend/menu.json` with no account and no key. What you
> lose is the voice, which is the part we host — see *Making it yours* below for
> running your own model instead.

## Step 6 — Run the backend

Pick one.

**On your laptop, to try it:**

```bash
cd backend && npm install
VENUE_KEY=msr_live_… node src/index.js
```

**As a container, for a real restaurant:**

```bash
docker build -t mesero-ai .
docker run -p 8787:8787 -e VENUE_KEY=msr_live_… mesero-ai
```

**Hosted, which is what a real deployment wants.** A diner uses their own mobile
data — they are not going to join the restaurant's WiFi before dinner — so the
table screen has to be reachable from the internet. `deploy/cloud/` has a
compose file with Caddy in front, which obtains and renews the certificate by
itself. See [`servidor.md`](servidor.md).

You should see:

```
  Mesero AI backend
  pack        mesero
  provider    gabotrix (gemini-live) venue=msr_live_7f3…
  carta       Your Restaurant (plataforma)
  http        http://localhost:8787
```

`carta … (plataforma)` means the key worked and your menu came down. If it says
`local`, the key did not resolve and it fell back to the file — which is
deliberate: a restaurant whose internet drops at seven in the evening still
serves dinner.

## Step 7 — Point the gadget at it

There are two doors. Take the first one if you have a laptop.

### From the browser, over the USB cable

Open the console on **Chrome or Edge on a computer** and use *Conectar gadget*.
It flashes the firmware, asks the gadget which WiFi networks *it* can see from
where it is standing, and writes the network, the table and the venue key down
the same cable. Nothing is typed on a phone.

This is also how somebody with no PlatformIO installed gets a working board:
steps 4 and 7 collapse into one button, and the toolchain never enters the
story.

> Web Serial exists only in desktop Chrome and Edge. Not Safari, not Firefox,
> and no mobile browser at all — which is exactly why the second door stays.

The same screen lives in **Conexión → Conectar un gadget** for a restaurant
that already exists. That is where the commonest errand happens: the WiFi
password changed. Plug the gadget in, pick the new network, save. It keeps its
venue key and its table — you only change what you came to change.

### Forgetting a network without forgetting everything

Holding **BOOT** on the gadget does two different things, and the difference
matters:

| Hold | What it forgets |
| --- | --- |
| 3 seconds | The WiFi network only. Venue key and table survive. |
| 10 seconds | Everything, for a gadget moving to another restaurant. |

Watch the serial monitor while you hold it — it says which one you are about to
get before you let go. This used to be a single gesture that wiped all of it,
so the price of a new WiFi password was finding a forty-character key again.

### From a phone, over the gadget's own WiFi

Power the gadget. It raises a WiFi network called **MeseroAI-setup**. Join it
from a phone and the setup page opens by itself.

The fastest way: in the console, open **Mesas**, press the QR button on the
table you are setting up, and scan it with the phone's camera. The page opens
with the table already filled in. Paste your venue key, choose the restaurant's
WiFi, and save.

> The portal cannot scan the code itself. A captive portal is plain HTTP at
> 192.168.4.1 and browsers refuse camera access outside a secure context — no
> library changes that. The phone's own camera app does the scanning.

Watch the monitor. You want:

```
[ws] connected
[ws] session s_4d448318
[mic] peak=8712 tx=1 | doa=301 vad=1
```

`tx=1` means audio is going out. `doa` is the bearing it is hearing.

## Step 8 — Write the NFC tag

With any NFC writer app, write a **URL record** to the sticker:

```
https://your-backend/?dock=mesa-01
```

The `dock` must match what you set on the gadget. That string is the only thing
pairing the gadget with the diner's phone — both open a socket to the backend
and are matched by it.

Lock the tag afterwards if the app offers it. Table stickers get picked at.

## Step 9 — Talk to it

Sit down. Say **"mesero"**, then order something from your carta.

What should happen: the LED ring points at you, the agent answers out loud, and
the dish appears on the phone screen attributed to *Cliente 1*. Have somebody
sitting elsewhere order something — they become *Cliente 2*, and their dish is
theirs.

Ask for the bill. It should ask which number to send the receipt to, read it
back to confirm, and send the payment link by WhatsApp.

---

## When it does not work

Every one of these happened to us. The symptom is what you will actually see.

### The board does not appear on USB at all

**Not a cable fault** — or not only. The reSpeaker ships in I2S mode, and in
that mode it does not enumerate as a USB device. Confirm the XIAO itself
enumerates; that is the board you flash.

### `[mic] peak=0` forever, nothing transmits

The XMOS chip is in the wrong mode, or the wrong I2S channel is being read.
Override the channel and reflash:

```bash
pio run -t upload --build-flag="-DMIC_CHANNEL=1"
```

We chased this as a wiring fault for an hour. It was a partial `i2s_read`: the
driver returns fewer bytes than asked for and the firmware was discarding the
remainder instead of accumulating across calls.

### The agent speaks in chops

The model emits a whole sentence at once and the device buffer overruns. The
backend meters delivery at real time to prevent exactly this, and holds a
cushion of frames before it starts playing so a slow patch of network does not
run the speaker dry mid-word. That cushion is `PRIME_FRAMES`, default 10. Lower
it and you get underruns; we measured 17 per reply before this existed.

### The agent hears itself and orders its own dinner

Genuinely happened. The turn was being ended at `turn_end`, which means the model
stopped *generating* — but playback trails generation by the whole length of the
queue, so the microphone gate opened while the speaker was still talking. The
turn ends when the queue drains, not when the model stops.

### You cannot interrupt it

Our first attempt gated barge-in on volume. Measured on the bench: the agent's
own voice returns at a peak of 19074 and a person speaking reaches 31545. No
threshold separates those. The XVF3800 runs its voice detector *after* echo
cancellation, so it stays quiet through the agent's own speech — that flag is
the answer, and four consecutive frames of it (80 ms) now cut the agent off.

### Everyone at the table is "Cliente 1"

Bearings were being read when the model called a tool, which is seconds after
the person stopped speaking — by then the register holds something stale. They
are sampled only while the array reports speech now, and cleared every turn.
Leaving them behind was its own bug: the next person's angles piled onto the
previous person's and the average landed at a point where nobody was sitting.

### `doa` is always 0

Firmware 1.0.4 of the XMOS chip has no DOA register. Update the reSpeaker to
1.0.6 or later. Then note that the register only updates once LED effect 4 has
been selected at least once — which is why that effect is the resting state.

### The LED ring stays dark

Effect 0 is *off*, not *solid*. And the colour command takes four bytes in the
order B, G, R, 0 — not three RGB.

### The gadget connects and is immediately dropped

`[ws] connected` followed at once by `[ws] disconnected`. The backend refused
it. Either the venue key on the gadget does not match the one the backend was
started with, or you are running a build from before device authentication —
check the server log for `device refused`.

### The backend dies the moment a gadget connects

`ReferenceError: WebSocket is not defined`. You are on Node 20, where the global
WebSocket does not exist — it became reliable in 22. The code imports the `ws`
client precisely so this does not happen; if you have edited a provider, do the
same.

### A feature silently does nothing

Check the boot log for a config error. Every tuning constant is asserted numeric
at startup because three of them once went missing from the config, and
`n >= undefined` is quietly `false` — the features simply switched themselves
off, with no error anywhere, and it looked like a hardware problem for a day.

---

## How it actually works

**The firmware is deliberately dumb.** It moves already-clean 16 kHz audio
between I2S and a WebSocket and reports the bearing. It does not know the menu,
when a turn ended, or which vendor answers. That is on purpose: changing a menu
must not mean unscrewing a table, restarting a server takes a second where
reflashing takes minutes, and the XMOS chip already does the heavy processing in
silicon.

**The phone never touches the hardware.** iOS Safari has neither Web Bluetooth
nor Web Serial, and it drops microphone permission when the screen locks. So the
two never talk to each other — both open a plain WebSocket to the backend and
are matched by the `dock` id the NFC tag encodes. Nothing on the phone asks for
a permission.

**The wire protocol** is eight bytes of header and then PCM16: magic, version,
type, flags, sequence, bearing. The bearing rides in the audio header because it
changes per frame. It is specified in [`protocolo.md`](protocolo.md), and the
firmware and the Python client implement it identically.

---

## Making it yours

**The carta, the tables, the agent's character and your colours** are all in the
console. The table screen reads your colours at load, so a change reaches every
table on the next tap — nothing rebuilt, nothing reflashed.

**A different domain entirely.** An agent pack owns the prompt, the tools the
model may call, and how a tool call changes the screen. Nothing else in the
stack knows what is being sold. A second pack is one file in
`backend/src/packs/` and one line in the registry.

**Your own voice model.** `PROVIDER=openai` uses your credential;
`PROVIDER=local` talks to a model on your own hardware and keeps working when
the internet does not. The contract for a local one is four messages in and four
out — see [`voz-local.md`](voz-local.md). An adapter in front of whisper.cpp and
a small model is about a hundred lines.

**No microphone array yet?** `device-client/` is a Python stand-in that speaks
the same protocol using your laptop's microphone. You can build and understand
the entire system before the hardware arrives.

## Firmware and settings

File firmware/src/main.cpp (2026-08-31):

/**
 * Mesero AI — gadget firmware for reSpeaker XVF3800 + XIAO ESP32S3.
 *
 * The XMOS keeps its factory I2S firmware and does the hard part in hardware:
 * acoustic echo cancellation, beamforming, noise suppression, and direction of
 * arrival. This firmware carries: it moves already-clean 16 kHz audio between
 * I2S and a WebSocket, and reports where the voice came from.
 *
 * It decides nothing on purpose. It does not know the menu, when a turn ended,
 * or which vendor answers. That logic lives in the backend for four reasons:
 * changing the menu must not mean unscrewing a table; restarting a server takes
 * a second where flashing, rebooting and re-provisioning take minutes; less code
 * on the device is fewer failures somewhere with no serial monitor attached; and
 * the XMOS already does the heavy processing in silicon, so repeating it here
 * would be slower and worse. The edge carries, the centre decides.
 *
 * First boot opens a WiFi portal named "MeseroAI-setup" where the network, the
 * backend address and the table id are entered. Hold the BOOT button during
 * reset to forget them.
 */

#include <Arduino.h>
#include <WiFi.h>
#include <WiFiManager.h>
#include <WebSocketsClient.h>
#include <ArduinoJson.h>
#include <Preferences.h>
#include <driver/i2s.h>

#include "protocol.h"
#include "xvf3800.h"
#include "portal_ui.h"

// ---------------------------------------------------------------- pinout
// Confirmed against the Seeed wiki for this board (I2S and UDP streaming
// examples both use these).
static const int PIN_I2S_BCLK = 8;
static const int PIN_I2S_WS = 7;
static const int PIN_I2S_DOUT = 44;  // ESP32 -> XVF3800 -> speaker
static const int PIN_I2S_DIN = 43;   // microphones -> ESP32
static const int PIN_BOOT_BUTTON = 0;

static const i2s_port_t I2S_PORT = I2S_NUM_0;

// The XVF3800 speaks 32-bit stereo at 16 kHz; the protocol wants 16-bit mono.
static const size_t I2S_FRAME_BYTES = DEVICE_FRAME_SAMPLES * 2 * 4;  // 2560

// Which I2S channel carries the beamformed, echo-cancelled speech. Override with
// -DMIC_CHANNEL=1 if the level log shows the voice on the right channel instead.
#ifndef MIC_CHANNEL
#define MIC_CHANNEL 0
#endif

// LED animation mode. 0 is a steady colour; 1 blinks. Override to explore other
// effects the XMOS firmware exposes.
#ifndef LED_EFFECT_SOLID
#define LED_EFFECT_SOLID 0
#endif

// The XMOS effect ids are undocumented. These two were identified on the bench
// by cycling every id and watching the ring:
//
//   4  blue ring with a single lit segment tracking the talker. Selecting it
//      also arms the azimuth register — on firmware before 1.0.8 DOA_VALUE
//      stays at zero until this effect has been chosen at least once.
//   1  every LED pulsing together in the chosen colour.
//
// Effect 0 is not "solid", it is off, which is why an earlier build left the
// ring dark.
#ifndef LED_EFFECT_DOA
#define LED_EFFECT_DOA 4
#endif
#ifndef LED_EFFECT_PULSE
#define LED_EFFECT_PULSE 1
#endif

// Playback jitter buffer. 500 ms is well past the 400 ms the protocol allows us
// to hold, so the drain logic below trims rather than the allocation.
static const size_t PLAYBACK_CAPACITY = 48000;  // 1.5 s of 16 kHz PCM16
static const size_t PLAYBACK_MAX_HOLD = DEVICE_FRAME_BYTES * 50;  // 1 s

// ---------------------------------------------------------------- globals

Preferences prefs;

/** The portal blocks inside setup(); loop() never touches it. */
WiFiManager wm;

static void startSocket();
static void checkProvisioningReset();
WebSocketsClient ws;
Xvf3800 xmos;

static String cfgHost;
static uint16_t cfgPort;
static String cfgDock;
/**
 * Issued by the console at console.gabotrix.com. It is what lets somebody build
 * this gadget without opening an account at a single vendor: paste it once here
 * and the backend knows which restaurant this table belongs to.
 *
 * Empty is fine — the backend then runs on the carta bundled in the repository,
 * which is how a first evening usually goes.
 */
static String cfgVenueKey;

static bool linkReady = false;   // backend sent `welcome`
static uint16_t txSeq = 0;
static uint16_t lastDoa = DOA_UNKNOWN;
static bool lastSpeech = false;
static uint32_t lastDoaPoll = 0;
static uint32_t doaPollInterval = 100;
static uint8_t doaFailures = 0;
static uint32_t lastTelemetry = 0;
static uint32_t pbUnderruns = 0;   // ran dry mid-sentence
static uint32_t pbDrops = 0;       // arrived faster than we could play

static uint8_t playback[PLAYBACK_CAPACITY];
static volatile size_t pbHead = 0;  // write
static volatile size_t pbTail = 0;  // read

static int32_t i2sIn[DEVICE_FRAME_SAMPLES * 2];
static int32_t i2sOut[DEVICE_FRAME_SAMPLES * 2];
static uint8_t txFrame[PROTO_HEADER_BYTES + DEVICE_FRAME_BYTES];

// ------------------------------------------------------------ ring buffer

static inline size_t pbAvailable() {
  size_t h = pbHead, t = pbTail;
  return (h >= t) ? (h - t) : (PLAYBACK_CAPACITY - t + h);
}

static void pbPush(const uint8_t *data, size_t len) {
  for (size_t i = 0; i < len; i++) {
    size_t next = (pbHead + 1) % PLAYBACK_CAPACITY;
    if (next == pbTail) {
      // Full: drop the oldest sample rather than fall further behind.
      pbTail = (pbTail + 2) % PLAYBACK_CAPACITY;
    }
    playback[pbHead] = data[i];
    pbHead = next;
  }
  // Never hold more than the protocol's ceiling.
  while (pbAvailable() > PLAYBACK_MAX_HOLD) {
    pbTail = (pbTail + DEVICE_FRAME_BYTES) % PLAYBACK_CAPACITY;
    pbDrops++;
  }
}

static void pbPop(uint8_t *out, size_t len) {
  for (size_t i = 0; i < len; i++) {
    out[i] = playback[pbTail];
    pbTail = (pbTail + 1) % PLAYBACK_CAPACITY;
  }
}

static void pbClear() {
  pbTail = pbHead;
}

// ------------------------------------------------------------------- LEDs

static void setLedState(const char *state) {
  if (!xmos.present()) return;

  // The backend announces a state change twice (agent_state and led). Acting on
  // both doubles the I2C traffic for no benefit.
  static char current[16] = "";
  if (!strncmp(current, state, sizeof(current))) return;
  strncpy(current, state, sizeof(current) - 1);
  current[sizeof(current) - 1] = 0;

  // Two states, two languages. While the diner has the floor the ring points at
  // whoever is speaking; while the agent answers the whole ring pulses in a
  // different colour, which reads as a voice rather than as a direction.
  if (!strcmp(state, "talking")) {
    xmos.setLedEffect(LED_EFFECT_PULSE);
    xmos.setLedColour(255, 70, 0);  // red-orange
    xmos.setLedSpeed(3);
    xmos.setLedBrightness(255);
  } else if (!strcmp(state, "thinking")) {
    xmos.setLedEffect(LED_EFFECT_PULSE);
    xmos.setLedColour(170, 0, 255);  // violet
    xmos.setLedSpeed(1);
    xmos.setLedBrightness(170);
  } else if (!strcmp(state, "listening")) {
    xmos.setLedEffect(LED_EFFECT_DOA);
    xmos.setLedColour(0, 255, 90);  // the tracking segment turns green
    xmos.setLedBrightness(220);
  } else {
    // Idle still tracks voices, just dimly — the table looks alive, and the
    // azimuth register stays armed for the moment somebody speaks.
    xmos.setLedEffect(LED_EFFECT_DOA);
    xmos.setLedColour(0, 200, 120);
    xmos.setLedBrightness(90);
  }
  Serial.printf("[led] %s\n", state);
}

// -------------------------------------------------------------------- I2S

static bool i2sStart() {
  i2s_config_t cfg = {};
  cfg.mode = (i2s_mode_t)(I2S_MODE_MASTER | I2S_MODE_RX | I2S_MODE_TX);
  cfg.sample_rate = DEVICE_RATE;
  cfg.bits_per_sample = I2S_BITS_PER_SAMPLE_32BIT;
  cfg.channel_format = I2S_CHANNEL_FMT_RIGHT_LEFT;
  cfg.communication_format = I2S_COMM_FORMAT_STAND_I2S;
  cfg.intr_alloc_flags = ESP_INTR_FLAG_LEVEL1;
  cfg.dma_buf_count = 8;
  cfg.dma_buf_len = DEVICE_FRAME_SAMPLES;  // one 20 ms block per DMA buffer
  cfg.use_apll = false;
  cfg.tx_desc_auto_clear = true;

  if (i2s_driver_install(I2S_PORT, &cfg, 0, nullptr) != ESP_OK) return false;

  i2s_pin_config_t pins = {};
  pins.mck_io_num = I2S_PIN_NO_CHANGE;
  pins.bck_io_num = PIN_I2S_BCLK;
  pins.ws_io_num = PIN_I2S_WS;
  pins.data_out_num = PIN_I2S_DOUT;
  pins.data_in_num = PIN_I2S_DIN;

  if (i2s_set_pin(I2S_PORT, &pins) != ESP_OK) return false;
  i2s_zero_dma_buffer(I2S_PORT);
  return true;
}

/// Reads one 20 ms block and ships it as a mic frame.
static bool captureAndSend() {
  // i2s_read returns whatever the DMA has ready, which for a 20 ms frame is
  // usually less than a full frame. Accumulate across calls: discarding partial
  // reads means never sending anything at all.
  static size_t filled = 0;

  size_t got = 0;
  esp_err_t err = i2s_read(I2S_PORT, ((uint8_t *)i2sIn) + filled, I2S_FRAME_BYTES - filled,
                           &got, pdMS_TO_TICKS(6));
  if (err != ESP_OK) return false;
  filled += got;
  if (filled < I2S_FRAME_BYTES) return false;
  filled = 0;

  // Convert to 16-bit mono. The XMOS sends 32-bit words with the audio in the
  // upper bits, so the top half is the sample we want.
  int16_t *pcm = (int16_t *)(txFrame + PROTO_HEADER_BYTES);
  int32_t peakL = 0, peakR = 0;
  for (size_t i = 0; i < DEVICE_FRAME_SAMPLES; i++) {
    int16_t l = (int16_t)(i2sIn[i * 2] >> 16);
    int16_t r = (int16_t)(i2sIn[i * 2 + 1] >> 16);
    if (abs(l) > peakL) peakL = abs(l);
    if (abs(r) > peakR) peakR = abs(r);
    pcm[i] = MIC_CHANNEL == 0 ? l : r;
  }

  // Periodic level report. If both peaks stay at zero the I2S wiring or format
  // is wrong; if only one moves, that is the channel carrying processed speech.
  static uint32_t lastLevelLog = 0;
  static int32_t holdL = 0, holdR = 0;
  if (peakL > holdL) holdL = peakL;
  if (peakR > holdR) holdR = peakR;
  uint32_t now = millis();
  if (now - lastLevelLog > 2000) {
    lastLevelLog = now;
    Serial.printf("[mic] peak=%ld tx=%u | doa=%u vad=%d | pb=%uB under=%u drop=%u\n",
                  (long)holdL, txSeq, lastDoa, (int)lastSpeech, (unsigned)pbAvailable(),
                  (unsigned)pbUnderruns, (unsigned)pbDrops);
    holdL = holdR = 0;
  }

  if (!linkReady || !ws.isConnected()) return true;

  uint8_t flags = lastSpeech ? FLAG_VAD : 0;
  txSeq++;
  protoWriteHeader(txFrame, FRAME_MIC, flags, txSeq, lastDoa);
  ws.sendBIN(txFrame, sizeof(txFrame));
  return true;
}

/**
 * Writes exactly one 20 ms block of agent speech.
 *
 * Called once per captured frame, which is what keeps playback smooth: input and
 * output share the same I2S clock, so consuming one frame for every frame
 * produced holds the two in lockstep. Draining the whole buffer in a burst — the
 * previous behaviour — starved the microphone read and the socket, and came out
 * of the speaker chopped.
 */
static void drainPlayback() {
  // Hold ~60 ms before starting so a late packet does not cause an underrun on
  // the very first word. Once running, keep going until the buffer truly empties.
  static bool playing = false;
  size_t avail = pbAvailable();
  if (!playing) {
    // Eight frames, not three. Sixty milliseconds of cushion was not enough to
    // ride out WiFi jitter: the buffer ran dry mid-sentence and the agent
    // audibly paused. This costs 100 ms of latency once, at the start of a turn.
    if (avail < DEVICE_FRAME_BYTES * 8) return;
    playing = true;
  }
  if (avail < DEVICE_FRAME_BYTES) {
    // Ran dry while a sentence was still playing: that is an audible gap.
    playing = false;
    pbUnderruns++;
    return;
  }

  uint8_t mono[DEVICE_FRAME_BYTES];
  pbPop(mono, DEVICE_FRAME_BYTES);

  int16_t *s = (int16_t *)mono;
  for (size_t i = 0; i < DEVICE_FRAME_SAMPLES; i++) {
    int32_t v = ((int32_t)s[i]) << 16;
    i2sOut[i * 2] = v;      // left
    i2sOut[i * 2 + 1] = v;  // right
  }

  size_t written = 0;
  i2s_write(I2S_PORT, i2sOut, I2S_FRAME_BYTES, &written, pdMS_TO_TICKS(10));
}

// -------------------------------------------------------------- WebSocket

static void sendHello() {
  StaticJsonDocument<384> doc;
  doc["t"] = "hello";
  doc["proto"] = 1;
  doc["dock"] = cfgDock;
  // Which restaurant this table belongs to. The backend's own VENUE_KEY wins
  // when it has one; this is here so a gadget can be traced to a venue from the
  // server log, and so a future direct-to-cloud mode has what it needs.
  if (cfgVenueKey.length()) doc["venue"] = cfgVenueKey;
  JsonObject dev = doc.createNestedObject("device");
  dev["id"] = String("xiao-") + String((uint32_t)ESP.getEfuseMac(), HEX);
  dev["model"] = "respeaker-xvf3800";
  dev["fw"] = "0.1.0";
  JsonObject audio = doc.createNestedObject("audio");
  audio["rate"] = DEVICE_RATE;
  audio["bits"] = 16;
  audio["ch"] = 1;
  audio["frameMs"] = DEVICE_FRAME_MS;
  JsonArray caps = doc.createNestedArray("caps");
  caps.add("doa");
  caps.add("vad");
  caps.add("aec");
  caps.add("beamforming");

  String out;
  serializeJson(doc, out);
  ws.sendTXT(out);
}

static void handleText(const uint8_t *payload, size_t length) {
  StaticJsonDocument<512> doc;
  if (deserializeJson(doc, payload, length)) return;
  const char *t = doc["t"] | "";

  if (!strcmp(t, "welcome")) {
    linkReady = true;
    Serial.printf("[ws] session %s\n", doc["session"] | "?");
  } else if (!strcmp(t, "agent_state")) {
    setLedState(doc["state"] | "idle");
  } else if (!strcmp(t, "audio_reset")) {
    // Barge-in. Everything already queued is stale the instant the diner speaks.
    pbClear();
    i2s_zero_dma_buffer(I2S_PORT);
  } else if (!strcmp(t, "sleep")) {
    pbClear();
    i2s_zero_dma_buffer(I2S_PORT);
    setLedState("idle");
  } else if (!strcmp(t, "led")) {
    setLedState(doc["mode"] | "idle");
  } else if (!strcmp(t, "ping")) {
    StaticJsonDocument<96> pong;
    pong["t"] = "pong";
    pong["ts"] = doc["ts"];
    String out;
    serializeJson(pong, out);
    ws.sendTXT(out);
  }
}

static void onWsEvent(WStype_t type, uint8_t *payload, size_t length) {
  switch (type) {
    case WStype_CONNECTED:
      Serial.println("[ws] connected");
      linkReady = false;
      pbClear();
      sendHello();
      break;

    case WStype_DISCONNECTED:
      // Name the target: a silent "disconnected" hides the usual cause, which
      // is the gadget dialling a host that is not there.
      Serial.printf("[ws] disconnected (target ws://%s:%u, own ip %s)\n", cfgHost.c_str(),
                    cfgPort, WiFi.localIP().toString().c_str());
      linkReady = false;
      pbClear();
      setLedState("idle");
      break;

    case WStype_TEXT:
      handleText(payload, length);
      break;

    case WStype_BIN: {
      uint8_t ftype = 0;
      const uint8_t *pcm = nullptr;
      size_t pcmLen = 0;
      if (protoParse(payload, length, &ftype, &pcm, &pcmLen) && ftype == FRAME_SPK) {
        pbPush(pcm, pcmLen);
      }
      break;
    }

    default:
      break;
  }
}

// ------------------------------------------------------------------- DOA

static void pollDoa() {
  uint32_t now = millis();
  if (now - lastDoaPoll < doaPollInterval) return;
  lastDoaPoll = now;

  uint16_t deg = 0;
  bool speech = false;
  if (!xmos.readDoa(&deg, &speech)) {
    // Back off rather than block the audio loop with I2C that keeps failing.
    if (doaFailures < 20 && ++doaFailures >= 10) doaPollInterval = 2000;
    return;
  }
  doaFailures = 0;
  doaPollInterval = 100;

  bool changed = (speech != lastSpeech);
  lastDoa = deg;
  lastSpeech = speech;

  // Telemetry is for the screen, not the audio path — keep it slow.
  if (linkReady && ws.isConnected() && (changed || now - lastTelemetry > 1000)) {
    lastTelemetry = now;
    StaticJsonDocument<128> doc;
    doc["t"] = "telemetry";
    doc["vad"] = speech;
    doc["doa"] = deg;
    String out;
    serializeJson(doc, out);
    ws.sendTXT(out);
  }
}

// ----------------------------------------------------------------- setup

// No address is baked in. A default that happens to be one developer's laptop
// is how a device ends up dialling a machine that does not exist on the venue's
// network. Set it in the portal, or pin it per deployment with
// -DDEFAULT_BACKEND_HOST=\"10.0.0.5\" in platformio.ini.
// The hosted backend. A diner is on their own mobile data, not the restaurant's
// WiFi, so the table screen has to be reachable from the internet — which means
// there is no useful local address to default to. Override for a local server.
#ifndef DEFAULT_BACKEND_HOST
#define DEFAULT_BACKEND_HOST "restaurant.gabotrix.com"
#endif
// Lets a bench provision a gadget without opening the portal — useful when the
// same key goes into twenty tables in a row. Never committed with a value in it:
// it is passed on the build command line.
#ifndef DEFAULT_VENUE_KEY
#define DEFAULT_VENUE_KEY ""
#endif

#ifndef DEFAULT_BACKEND_PORT
#define DEFAULT_BACKEND_PORT 443
#endif
#ifndef DEFAULT_DOCK
#define DEFAULT_DOCK "mesa-01"
#endif

static void loadConfig() {
  // Opening read-write creates the namespace, which keeps the first boot from
  // logging an NVS "NOT_FOUND" error.
  prefs.begin("mesero", false);
  cfgHost = prefs.getString("host", DEFAULT_BACKEND_HOST);
  cfgPort = prefs.getUShort("port", DEFAULT_BACKEND_PORT);
  cfgDock = prefs.getString("dock", DEFAULT_DOCK);
  cfgVenueKey = prefs.getString("venue", "");
  prefs.end();
}

static void saveConfig(const String &host, uint16_t port, const String &dock,
                       const String &venueKey) {
  prefs.begin("mesero", false);
  prefs.putString("host", host);
  prefs.putUShort("port", port);
  prefs.putString("dock", dock);
  prefs.putString("venue", venueKey);
  prefs.end();
}

// ------------------------------------------------------- provisioning by wire
//
// The browser can configure this gadget over the same USB cable it was flashed
// with, so nobody has to join a captive portal and type a forty-character venue
// key on a phone keyboard. Chrome's Web Serial opens the port, sends one JSON
// line, and we store it and reboot.
//
// The captive portal stays. Web Serial exists only in desktop Chrome and Edge —
// no Safari, no Firefox, no mobile browser at all — so a restaurant with only a
// phone still needs the portal. This is a second door, not a replacement.
//
// Replies are prefixed because this port is also the log stream, and the
// browser has to pick its answers out of a running commentary about I2S frames.
static const char *WIRE_TAG = "#MESERO ";
/** Defined below, next to the code that opens the socket. */
static bool wsStarted;
static String wireLine;

static void wireReply(const JsonDocument &doc) {
  Serial.print(WIRE_TAG);
  serializeJson(doc, Serial);
  Serial.println();
}

static void wireError(const char *why) {
  StaticJsonDocument<128> out;
  out["ok"] = false;
  out["error"] = why;
  wireReply(out);
}
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
void loop() {
  // The cable answers from the first second, network or no network. Reading
  // Serial.available() costs nothing; the captive portal, which briefly lived
  // here, cost the audio loop everything.
  pollWire();
  checkProvisioningReset();

  startSocket();
  if (!wsStarted) {
    watchWifi();
    return;
  }

  ws.loop();
  watchWifi();
  pollDoa();
  // One frame out for every frame in. Input and output share the I2S clock, so
  // this pacing is what keeps the speaker smooth.
  if (captureAndSend()) drainPlayback();
}

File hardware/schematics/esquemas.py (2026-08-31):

# -*- coding: utf-8 -*-
"""Generates the two schematics, and renders them to PNG and PDF.

    python esquemas.py

Written as code rather than drawn by hand for two reasons. The pin numbers are
read straight out of the firmware, so a pin that moves in the source can be
corrected here in one place. And arrowheads are emitted as polygons instead of
SVG markers: the renderer that produces the PNG and the PDF ignores markers,
which silently strips the direction out of a signal diagram.
"""
import math
import os

OUT = os.path.dirname(os.path.abspath(__file__))

INK = "#1A1411"
BODY = "#4A423C"
DIM = "#5C534C"
FAINT = "#7A6E66"
RULE = "#D8CEC5"
RED = "#C9331F"
WASH = "#FBF9F7"
REDWASH = "#FFF4F2"
FONT = "Helvetica, Arial, sans-serif"


def esc(t):
    return t.replace("&", "&amp;").replace("<", "&lt;").replace(">", "&gt;")


def txt(x, y, s, size=14, fill=BODY, weight=None, anchor=None, spacing=None):
    a = ['x="%g" y="%g" font-size="%g" fill="%s"' % (x, y, size, fill)]
    if weight:
        a.append('font-weight="%s"' % weight)
    if anchor:
        a.append('text-anchor="%s"' % anchor)
    if spacing:
        a.append('letter-spacing="%g"' % spacing)
    return "  <text %s>%s</text>" % (" ".join(a), esc(s))


def box(x, y, w, h, fill="#FFFFFF", stroke=INK, width=2, r=10, dash=None):
    d = ' stroke-dasharray="%s"' % dash if dash else ""
    return ('  <rect x="%g" y="%g" width="%g" height="%g" rx="%g" fill="%s" '
            'stroke="%s" stroke-width="%g"%s/>' % (x, y, w, h, r, fill, stroke, width, d))


def head(x1, y1, x2, y2, colour, size=9):
    """An arrowhead as a polygon — markers do not survive the PNG/PDF render."""
    ang = math.atan2(y2 - y1, x2 - x1)
    pts = []
    for a, r in ((0, 0), (math.pi - 0.42, size * 1.25), (math.pi + 0.42, size * 1.25)):
        pts.append("%g,%g" % (x2 + r * math.cos(ang + a), y2 + r * math.sin(ang + a)))
    return '  <polygon points="%s" fill="%s"/>' % (" ".join(pts), colour)


def arrow(x1, y1, x2, y2, colour=INK, width=2.5, dash=None, both=False):
    d = ' stroke-dasharray="%s"' % dash if dash else ""
    out = ['  <line x1="%g" y1="%g" x2="%g" y2="%g" stroke="%s" stroke-width="%g"%s/>'
           % (x1, y1, x2, y2, colour, width, d), head(x1, y1, x2, y2, colour)]
    if both:
        out.append(head(x2, y2, x1, y1, colour))
    return "\n".join(out)


def curve(path, colour=INK, width=2, dash=None):
    d = ' stroke-dasharray="%s"' % dash if dash else ""
    return '  <path d="%s" fill="none" stroke="%s" stroke-width="%g"%s/>' % (
        path, colour, width, d)


def masthead(title, sub, right1, right2, w=1600):
    return "\n".join([
        '  <rect width="%g" height="100%%" fill="#FFFFFF"/>' % w,
        txt(60, 62, title, 34, INK, "700"),
        txt(60, 90, sub, 16.5, DIM),
        txt(w - 60, 62, right1, 15, INK, "700", "end"),
        txt(w - 60, 86, right2, 13, FAINT, anchor="end"),
        '  <line x1="60" y1="112" x2="%g" y2="112" stroke="%s" stroke-width="2"/>' % (w - 60, RULE),
    ])


def footer(y, lines, w=1600):
    out = ['  <line x1="60" y1="%g" x2="%g" y2="%g" stroke="%s" stroke-width="2"/>'
           % (y, w - 60, y, RULE)]
    for i, l in enumerate(lines):
        out.append(txt(60, y + 32 + i * 26, l, 14, DIM))
    out.append(txt(60, y + 32 + len(lines) * 26 + 6,
                   "Apache-2.0 · github.com/gabotrix/mesero-ai · Seeed Interactive Signage Contest 2026",
                   13, FAINT))
    return "\n".join(out)


def document(w, h, title, desc, body):
    return ('<svg xmlns="http://www.w3.org/2000/svg" viewBox="0 0 %g %g" width="%g" '
            'height="%g" font-family="%s">\n  <title>%s</title>\n  <desc>%s</desc>\n%s\n</svg>\n'
            % (w, h, w, h, FONT, esc(title), esc(desc), body))


# ── diagram 1 · how the three pieces connect ─────────────────────────
def conexiones():
    W, H = 1600, 1000
    p = [masthead("Mesero AI — connection diagram",
                  "Every connection in the build. The gadget hears; the phone only shows.",
                  "GABOTRIX AI®", "reSpeaker XVF3800 + XIAO ESP32S3")]

    # ── the dock
    p += [box(60, 150, 600, 650, WASH, INK, 2.5, 14),
          txt(86, 184, "ON THE TABLE — THE GADGET", 13, RED, "700", spacing=1.5)]

    p += [box(90, 196, 540, 126),
          txt(112, 227, "reSpeaker XVF3800", 19, INK, "700"),
          txt(112, 250, "Seeed 114993700 · XMOS DSP · firmware 1.0.5", 13.5, DIM),
          txt(112, 271, "4 microphones on a 66 mm circle", 13.5, DIM),
          txt(112, 292, "Echo cancellation, beamforming, VAD, direction of arrival", 13.5, DIM),
          txt(112, 313, "Class-D amplifier on board", 13.5, DIM)]
    for cx, cy in ((566, 233), (596, 256), (566, 279), (536, 256)):
        p.append('  <circle cx="%g" cy="%g" r="6.5" fill="%s"/>' % (cx, cy, RED))

    # the two buses, drawn as real arrows so direction survives
    p += [arrow(200, 318, 200, 392, INK, 2.5, both=True),
          box(150, 332, 104, 46, "#FFFFFF", INK, 1.5, 6),
          txt(202, 351, "I²S audio", 13, INK, "700", "middle"),
          txt(202, 369, "16 kHz · 32 bit", 11, DIM, anchor="middle"),
          arrow(470, 318, 470, 392, INK, 2.5, both=True),
          box(420, 332, 104, 46, "#FFFFFF", INK, 1.5, 6),
          txt(472, 351, "I²C control", 13, INK, "700", "middle"),
          txt(472, 369, "0x2C · 100 kHz", 11, DIM, anchor="middle")]

    p += [box(90, 392, 540, 104),
          txt(112, 422, "XIAO ESP32S3", 19, INK, "700"),
          txt(112, 445, "Seats on the array's 14-pin header — no loose wires", 13.5, DIM),
          txt(112, 466, "Streams 20 ms PCM frames; holds Wi-Fi and the venue key", 13.5, DIM),
          txt(112, 487, "BOOT on GPIO0: 3 s clears Wi-Fi · 10 s clears everything", 13.5, DIM)]

    p += [arrow(360, 496, 360, 556, RED, 2.5),
          txt(374, 530, "amplified out", 13, RED),
          box(150, 556, 400, 82),
          txt(172, 585, "Speaker · 8 Ω, 5 W", 18, INK, "700"),
          txt(172, 607, "Seeed 114993346 · 50 × 45 × 22 mm", 13.5, DIM),
          txt(172, 628, "Fires down through the floor of the base", 13.5, DIM)]

    p += [arrow(200, 700, 200, 502, INK, 2.5),
          box(90, 700, 230, 52),
          txt(112, 722, "USB-C — 5 V", 15, INK, "700"),
          txt(112, 741, "power · flashing · provisioning", 12, DIM),
          box(360, 700, 270, 52, "#FFFFFF", INK, 2, 8, dash="6 4"),
          txt(382, 722, "NTAG213 sticker", 15, INK, "700"),
          txt(382, 741, "passive — no power, no wires", 12, DIM)]
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

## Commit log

2026-08-30 Mesero AI: a voice waiter that lives in the table
    A conversational ordering assistant built on the reSpeaker XVF3800 four-mic
    array and a XIAO ESP32S3. Diners talk to the table; the gadget listens and
    answers; their phone only follows along and never asks for a microphone.
    The array reports the direction every phrase came from, so the agent knows who
    at the table is speaking and each dish is attributed to whoever asked for it —
    without anybody typing a seat number.
    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
    [base.3mf, calib.3mf, lid.3mf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]
2026-08-30 Resolve the venue key without carrying any other credential
    The config pull went through PostgREST, which demands the project's anon key —
    and that key cannot live in an open repository: on this project it also opens
    the payment and messaging functions. It now goes through an edge function,
    which demands nothing, so a venue key really is the only thing a restaurant
    configures. Verified with nothing else set at all.
    And the README was claiming more than is true. The voice is a hosted service
    and now refuses a connection without a valid key, so "hear the whole thing work
    with no configuration" was false. The screens, the order state, the kitchen
    board, the protocol and the firmware all run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
2026-08-30 Send the venue key when asking for a payment link
    The payment and messaging functions now authenticate the caller by its venue
    key, and the backend was not sending one — so a restaurant could take orders
    all evening and then discover at the till that it could not charge anybody.
    Caught by running the whole thing from a clean clone rather than by reading it.
    The anon key goes with it. It was never what those functions checked, and it
    has no business in an open repository.
2026-08-30 Let the container write its own cache, and survive when it cannot
    Railway crashed in a loop on boot: EACCES opening /app/backend/menu.json. The
    image runs as `node` while everything copied in belongs to root, and the carta
    pulled from the platform is cached back to that file.
    Two fixes, and the second matters more. The image now hands /app to the user
    that runs it. And a failed cache write no longer stops anything: the carta is
    already in memory by then, so a read-only filesystem is a warning, not a
    restaurant that cannot open. Verified against an unwritable menu.json — it
    warns and serves the platform carta anyway.
2026-08-30 Put the Dockerfile at the repository root
    Railway ignored the pointer to it under deploy/ and fell back to its own
    language detector, which cannot make sense of a repository holding firmware,
    CAD, a Python client and a Node backend at once — it looked for start.sh and
    gave up.
    At the root it is found without being told, on any platform, and `docker build
    .` works with no arguments. The build context was already the repository root,
    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
2026-08-30 Let a gadget prove itself with its venue key
    The device socket asked for a `token` it never compared against anything: any
    non-empty string opened the door, and the firmware sent none at all. So the flag
    that turns the check on was either theatre or a wall — with it off, anyone could
    attach to any table; with it on, as recommended for a public address, every real
    gadget in the restaurant would have been refused and every table left silent.
    The venue key replaces it. The firmware already carries one, it is the same
    credential the voice, the payments and the carta check, and it actually says
    which restaurant is calling. A backend with no venue key configured is somebody
    running the open-sou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
2026-08-30 Do not reach for a WebSocket the runtime may not have
    The voice bridge used the global WebSocket. It became reliable in Node 22 and
    this package declares Node 20, so the container — built on node:20 — threw
    "WebSocket is not defined" the instant a gadget connected and the session
    reached for the bridge, and took the whole process down with it. Every local
    test passed, on a machine running 22.
    It uses the `ws` client now, which is already a dependency and behaves the same
    on every version. Verified: 142 frames of speech came back.
    The test harness presents a venue key too. Devices have to authenticate since
    the token check was replaced, so a developer running these against a configured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
2026-08-30 Let the agent cut itself off, and take the number itself
    Two things a real table found.
    Interrupting her did not work. The gate was right — the array's detector runs
    after echo cancellation, so it stays quiet through her own voice — but all it
    did was forward those frames and hope the model noticed. It could not: while
    she speaks the only frames we forward are the flagged ones, so what reaches the
    model is a stream that starts mid-word, which is exactly what a voice detector
    ignores. We have the better detector. Four consecutive speech frames — 80 ms —
    now flush playback and cancel the response outright.
    And asked for the bill, she sent people to find a waiter. She is the waiter.
    r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
2026-08-30 Let a restaurant's table screen wear its own colours
    Every table looked like ours regardless of whose restaurant it was, which is a
    strange thing to hand a diner. The venue now carries a logo and two colours,
    they ride along with the carta the backend already fetches with its venue key,
    and the screen applies them on load — so a change in the console reaches every
    table on the next tap, with nothing rebuilt and nothing reflashed.
    Setting --primary alone was not enough: the gradients behind the header and the
    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
2026-08-30 Three ways to give this a voice, chosen with one variable
    A venue key and nothing else, your own OpenAI credential, or a model on your own
    hardware. The device, the session and the table screen cannot tell which is
    running — they all see the same eight events.
    The local path is the one that matters for a restaurant with bad internet: every
    other option here dies with the connection, and dinner does not. It speaks the
    same envelope as the hosted bridge on purpose, so an adapter in front of
    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
2026-08-30 Write the build guide: empty desk to a talking table
    Nine steps, three hours, most of it printing. Written for somebody who has not
    seen this before, so it starts with the calibration coupon — ten minutes against
    four hours of lid, and two numbers in the case are not published in any Seeed
    datasheet.
    The troubleshooting section is the part worth having. Every entry is a failure
    we hit, described by what it looked like at the time rather than by its cause:
    the board that does not enumerate because it ships in I2S mode, the agent that
    hears itself and orders its own dinner, the barge-in that cannot work on volume
    because echo returns at 19074 against speech at 31545, the table where everyon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
2026-08-30 Give the kitchen a pass to work from
    The kitchen view was a redirect into the POS. It is a screen of its own now,
    built the way the reference one is: three columns left to right in the order a
    dish moves — sent, on the stove, ready to go out — with the ticket's table, its
    dishes, who at that table asked for each, and a clock that turns red and pulses
    at fifteen minutes, which is when a diner starts looking around for somebody to
    ask.
    A three-tone chime when something new lands, mutable. One beep in a kitchen is
    indistinguishable from a timer, an extractor fan or a phone; a rising-falling-
    rising figure is recognisable across a room full of noise, which is the whole
    job. It stays quiet o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
2026-08-30 Let the restaurant choose what language the agent serves in
    The prompt hardcoded Spanish and English. `agents.languages` has been a
    text[] on the platform all along and already arrived here inside the agent
    row — applyAgent simply dropped it on the floor.
    The IDIOMA block is now generated from that list. One language gets an
    instruction to stay in it and simplify rather than switch, because
    switching to a language the carta does not exist in helps nobody order.
    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
2026-08-30 Let the agent actually move the screen, and speak the diner's language
    The screen was never following the agent. show_menu set a category on the
    backend and web/app.js read `model.activeCategory` — a value only ever
    written by tapping a chip. The agent's choice has not once reached the
    glass.
    The view logic made it worse. It moved when `screen` *became* 'menu', so
    once the carta was open every later request was invisible: the drinks, then
    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
2026-08-30 Make the table able to say it does not know who spoke
    The bearing estimate had no notion of confidence, so it always returned
    one. Two people talking over each other averaged to the empty space between
    them and the dish went to whoever was sitting there — the failure the
    comment in the code warned about, guarded only by window length.
    Three changes, and the first is the one that matters.
    The estimator now returns a strength alongside the angle: the mean
    resultant length R, how much the samples agreed. Below 0.85 the turn is
    left unattributed instead of guessed, and a turn that cannot be estimated
    no longer inherits the previous speaker's bearing. An unattributed dish is
    a smaller failure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
2026-08-30 Fix three things a real table found that no simulation would
    Tested on hardware with several diners. Three faults, and the first one
    quietly destroyed the feature the whole project exists for.
    Two people ordering the same drink collapsed into one line. `find(sku)`
    matched on the dish alone, so the second lemonade incremented the first
    person's line and the second diner vanished from their own order — visible
    on screen as "2 × Limonada de coco · Cliente 3" when two different people
    had each asked for one. Matching is now per dish *and* per seat, and the
    edit tools act on the speaker's own line first, so "take that off" removes
    yours rather than your friend's. Unattributed lines still mer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
2026-08-30 Stop the table screen scrolling sideways on a phone
    The view area is a grid item, and a grid item defaults to min-width:auto —
    it refuses to shrink below the intrinsic width of what it holds. The step
    rail and the category chips are both wider than a phone, so the item pushed
    its own track out to 417px inside a 375px column and the whole page gained
    42px of horizontal scroll.
    Both of those already scroll inside themselves. They only needed permission
    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
2026-08-30 Let a browser configure the gadget over the cable it flashed it with
    Setting one of these up meant installing PlatformIO, then joining a captive
    portal from a phone and typing a forty-character venue key on a phone
    keyboard while standing at a table. Both of those are places people stop.
    The firmware now reads JSON lines on the port it already logs to. Three
    commands: identify yourself, list the WiFi networks you can see, and here is
    your configuration. Replies carry a `#MESERO ` prefix because that port is
    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
2026-08-30 Scan for networks with the radio that can see them
    The captive portal leaves the ESP32 in AP mode, and scanNetworks() in
    AP-only returns zero. So the browser was handed an empty list at exactly
    the moment somebody was standing there trying to pick a network — the one
    job this screen has. AP_STA now, which keeps the portal alive for whoever
    might be mid-session on it while the scan runs.
    hello also reports the radio: the network it is on, its address, signal,
    and whether the socket ever opened. From the console, 'cannot reach the
    network' and 'the server refused me' look identical and have opposite
    fixes; now they can be told apart without a serial monitor.
    [main.cpp]
2026-08-30 Make a refused gadget visible instead of silent
    A device with the wrong key gets its socket closed and says nothing anyone
    can reach. The console shows a table that never wakes, and the reason lives
    only in the server's stdout — which for a hosted deployment means a
    dashboard nobody has open while standing at the table with a cable.
    So "the gadget will not connect" had two completely different causes that
    looked identical from outside: it never arrived, or it arrived and was
    turned away. Different fixes, no way to tell which.
    /api/devices now reports what the server expects and the last twenty
    attempts with their outcome. Never the key itself — the first thirteen
    characters are enough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
2026-08-30 Let hello say which key the gadget is carrying
    Only whether one was present, never which — so a gadget holding a left-over
    credential from an old test looked exactly like a correctly provisioned one
    until the server refused it, silently, at the table.
    The first 17 characters is the same slice the platform stores as a key's
    prefix, which lets the console compare against the keys it issued and say
    'that is not one of this restaurant's' before anything is saved. Enough to
    identify a key, not enough to use one.
    [main.cpp]
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2026-08-31 Put the captive portal back where it was working
    Driving the portal from loop(), so the USB cable could answer a gadget with
    no network, was the right idea and I could not land it safely. Two
    regressions in one evening on a board standing in a restaurant: the first
    left an access point running that starved the audio loop until the XMOS
    reported neither voice activity nor direction, and the second rebooted the
    board every few seconds by switching WiFi mode underneath a TLS handshake
    that had only just begun.
    So autoConnect blocks again, exactly as it did all day without complaint,
    and loop() goes back to what its own comments say it needs: one frame out
    for every frame in, and nothing else i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
    [main.cpp]
2026-08-31 Keep the radio awake
    The firmware never touched WiFi power saving, so it ran with Arduino's
    default: modem sleep on, the radio dozing between beacons and waking to
    check for traffic. That is right for a sensor that reports once a minute and
    wrong for this, which streams a 20 ms audio frame each way without pause.
    It shows up as latency spikes and dropped frames on any network, and as an
    outright connect-and-drop cycle on a phone hotspot, which runs its own
    aggressive power saving from the other side. It is very likely part of the
    choppy playback too — this has been here since the beginning, not something
    tonight introduced.
    It costs current, and a gadget on a table is plugged in.
    Also l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
    [main.cpp]
2026-08-31 Answer the cable before there is a network, without the portal
    Third arrangement of this tonight, and the first that serves the case that
    actually happens.
    autoConnect() blocks inside setup() while it runs the portal, and pollWire()
    lives in loop(). So a gadget that could not reach its network could not be
    reached by the cable either — a deadlock at exactly the moment somebody is
    standing there trying to fix the network. That is what "the platform does not
    even recognise it" was.
    Stored credentials now mean WiFi.begin() and straight on to loop(), where the
    cable answers within a second whether or not the network ever comes up. The
    blocking portal is kept only for a board that has never b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
    [main.cpp]
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2026-08-31 Show the printed dock where the case is printed
    The exploded render belongs to the design, not to the step that tells you
    to print it — what you want to see there is what comes off the bed. This
    reuses the photo the cover replaced at the top.
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2026-08-31 Draw the two schematics the build actually has
    A project with a microphone array and an amplifier reads as though it
    should ship a circuit diagram, and there is no circuit: the XIAO seats on
    the array's header, the speaker plugs into a fitted connector, and the tag
    is passive. What is worth drawing is the signal map, whose pin numbers
    cannot be guessed, and the isolation between the phone and the gadget.
    Generated from esquemas.py so a pin that moves in the firmware is
    corrected in one place. Arrowheads are polygons, not SVG markers: svglib
    drops markers, which silently strips the direction out of every signal.
    [esquemas.py]
2026-08-31 Stop Git from rewriting the line endings inside binaries
    Git guesses binary by looking for NUL bytes near the start of a file. A
    PDF has none, so it was taken for text and its line endings were rewritten
    on checkout. A Windows clone came out 86 bytes heavier and the schematics
    no longer opened; 3MF print files were exposed to the same thing.
    Shell scripts and the systemd unit are pinned to LF for the opposite
    reason: they are read on Linux, where CRLF breaks the shebang line.

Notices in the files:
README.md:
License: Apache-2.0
